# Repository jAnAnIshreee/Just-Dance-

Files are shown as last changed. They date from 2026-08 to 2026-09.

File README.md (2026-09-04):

# Just-Dance-
A from-scratch reimagining of the Wii game "Just Dance": custom motion controller hardware (TM4C ARM Cortex-M4, SPI IMU, DAC audio) running on-device ML for real-time dance recognition, with MQTT syncing multiple controllers over Wi-Fi. Group project.
 # TinyML Embedded Gesture Classifier

I built this project with a team of individuals as a real-time embedded gesture-recognition system with a custom PCB using TM4C123 microcontrollers, LSM6DSOX IMUs, ESP8266 wireless communication, and fixed-point TinyML inference.

<p align="center">
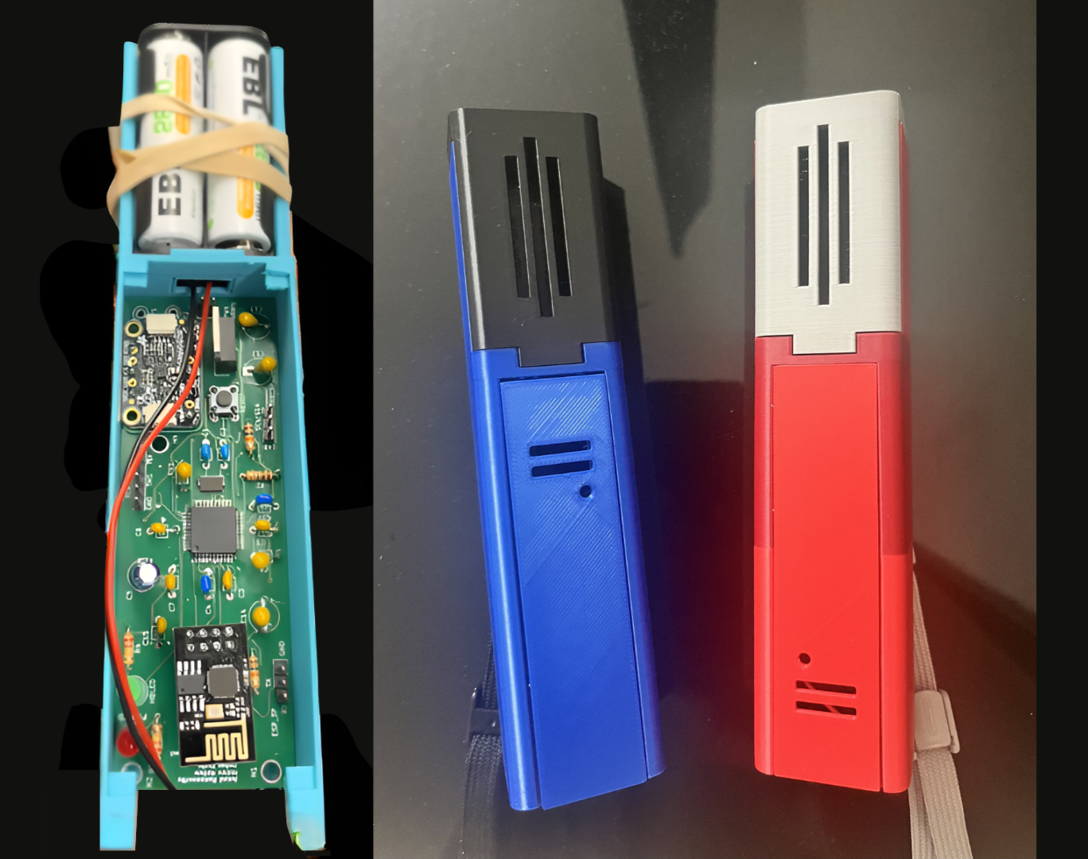
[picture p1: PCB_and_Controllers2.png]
  
</p>

<p align="center">
  <em>Custom PCB and handheld controller modules used in the embedded gesture classification system</em>
</p>

The system captures motion from handheld controller modules, segments raw IMU data into meaningful gesture windows, extracts engineered features, runs lightweight classifiers directly on-device, and streams results to a central hub and host display. The full pipeline runs on embedded hardware rather than relying on a PC for inference.

---

## Overview

My goal with this project was to design a complete embedded system capable of classifying human motion under tight hardware constraints.

Each controller:

* samples a 6-axis IMU in real time
* performs filtering and calibration
* segments motion into gesture windows
* extracts a compact feature vector
* classifies gestures using rule-based logic and TinyML models

A central hub coordinates timing, aggregates controller outputs over ESP8266, and forwards results to a PC over UART for visualization.

---

## Key Features

* Real-time gesture classification on TM4C123 microcontrollers
* LSM6DSOX accelerometer/gyroscope integration over I2C
* Deterministic scheduling using a free-running hardware timer
* Fixed 5-second calibration stage for bias stabilization
* Tunable motion segmentation engine
* 32-feature embedded feature extraction pipeline
* Fixed-point TinyML inference (no floating point at runtime)
* Hybrid detection: neural networks + rule-based scoring
* ESP8266 wireless communication between modules
* UART protocol for structured output (`SEG` and `DETECT`)
* EEPROM-backed configuration persistence
* Multi-module embedded architecture (controllers + hub + host)

---

## System Architecture

```text
Controller Modules (TM4C + IMU)
    ↓
Sensor processing + segmentation
    ↓
Feature extraction (32 features)
    ↓
TinyML / rule-based classification
    ↓
ESP8266 wireless messages
    ↓
Central Hub (TM4C)
    ↓
UART output
    ↓
Host PC (Python visualization/logging)
```

A key design decision I made was to keep all classification on the embedded controllers. The PC is only used for visualization and logging, not inference.

---

## Repository Structure

```text
sw/
  sw_Player1_Controller/   → Controller firmware
  sw_Player2_Controller/   → Second controller firmware
  sw_Audio/                → Central hub firmware
  sw_Display/              → Python host interface

hw/                        → KiCad hardware design files
Resources/                 → Datasheets and references
```

### Main Entry Points

* `sw_Player1_Controller/src/Lab1.c`
* `sw_Player2_Controller/sw/src/Lab1.c`
* `sw_Audio/sw/src_latest/Lab5.c`

---

## Embedded Gesture Pipeline

Each controller runs a full embedded ML pipeline:

```text
IMU read
→ axis remap
→ filtering
→ calibration
→ segmentation
→ feature extraction
→ classification
→ output
```

### IMU Processing

I read accelerometer and gyroscope data over I2C and remap axes into a consistent real-world coordinate system:

```text
IRL X = sensor Y  
IRL Y = sensor Z  
IRL Z = sensor X  
```

---

### Calibration

At startup, I run a strict 5000 ms calibration phase using timer-based scheduling. This avoids drift and ensures stable baseline values for bias and gravity compensation.

---

### Real-Time Scheduling

I use Timer0A as a free-running hardware timer and schedule all sampling relative to time instead of loop delays. This keeps behavior deterministic even with UART output or I2C latency.

---

### Motion Segmentation

I designed a segmentation engine that detects meaningful motion using:

* energy thresholds
* quiet-window detection
* min/max segment sizes
* cooldown timing

Each gesture can override segmentation parameters, which makes the system flexible across very different motion types.

---

## Feature Extraction

For each segment, I compute 32 engineered features describing motion shape and intensity.

Examples include:

* duration and sample count
* vertical displacement and total travel
* cross-body movement
* oscillation and slope changes
* total acceleration and gyro energy
* peak timing and normalized feature ratios
* spin characteristics
* energy per sample

Instead of feeding raw time-series data into a large model, I compress each gesture into a compact feature vector to stay within embedded constraints.

---

## TinyML Inference

I implemented small neural networks directly in firmware using fixed-point math.

Typical structure:

```text
16 inputs → 3 hidden (ReLU) → 1 output
```

All weights, biases, and normalization parameters are stored as scaled integers. This avoids floating-point overhead and keeps inference fast and deterministic.

Some gestures use ML models, while others use rule-based scoring depending on how well they can be defined analytically.

---

## Output Protocol

The system outputs structured UART messages:

### Feature Data

```text
SEG,<MOVE>,<32 values>
```

### Final Detection

```text
DETECT,<MOVE>,<score>
```

I use `SEG` for debugging/training and `DETECT` as the final classification output.

---

## Cumulative Scoring

Instead of classifying every segment independently, I accumulate scores across a gesture window and only output a final detection after enough evidence is collected.

This significantly reduces noise and false positives.

---

## Central Hub

The hub is another TM4C system that:

* synchronizes controller start timing
* receives wireless data from controllers
* forwards results over UART
* manages timing-sensitive coordination

---

## Host Interface

I wrote a Python interface using:

* `pyserial` for communication
* `tkinter` for UI
* `opencv` / `Pillow` for visualization

This layer is purely for monitoring—the embedded system performs all classification.

---

## Hardware

This system is built on:

* TM4C123 microcontrollers
* LSM6DSOX IMUs
* ESP8266 modules
* DAC/audio hardware (hub side)
* custom KiCad-designed boards

All hardware files are included in the `hw/` directory.

---

## Why This Project Matters

This project combines:

* real-time embedded systems
* IMU signal processing
* motion segmentation
* feature engineering
* TinyML on constrained hardware
* wireless embedded communication

The most important aspect is that the entire ML pipeline runs **on-device**, making it a true embedded TinyML system rather than a PC-based demo.

---

## Future Improvements

* Modularize controller firmware
* Formalize ML training/export pipeline
* Add evaluation metrics (accuracy, confusion matrix)
* Improve host visualization tools
* Add hardware/system diagrams

---

## Status

This is a working embedded system prototype with real-time gesture classification, multi-device coordination, and on-device ML inference. The core pipeline is fully implemented and functional on embedded hardware.

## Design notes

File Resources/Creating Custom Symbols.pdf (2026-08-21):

## Creating Custom Symbols

## Contents

Creating Custom Symbols | 1

Introduction

KiCad is a powerful open-source software suite for electronic design automation (EDA). It offers a comprehensive set of tools for schematic capture and PCB layout. While KiCad comes with an extensive library of symbols and footprints, there are times when you may need to create custom symbols and footprints to suit specific components or devices not available in the standard libraries or online.

Creating custom symbols allows you to represent components accurately in your schematics, while custom footprints enable precise placement and routing of PCB components.

Creating a Custom Symbol

A symbol in KiCad represents a component on your schematic. Every component on a schematic must be precisely represented to ensure the functionality and reliability of the final product. While KiCad offers a vast library of pre-made symbols, there are instances where designers encounter unique components or specialized devices not covered by the standard offerings.

To create a symbol, open the symbol editor.

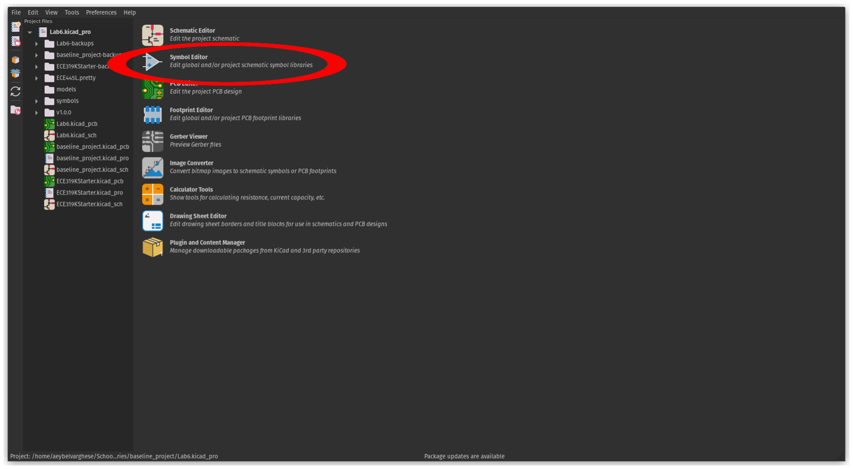
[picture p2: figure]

Figure 1: Main Menu

The KiCad Symbol Editor is a tool within the KiCad software suite specifically designed for creating and editing schematic symbols. It provides a user-friendly interface for designing graphical representations of electronic components, which are then used in schematics to illustrate circuit connections and layouts.

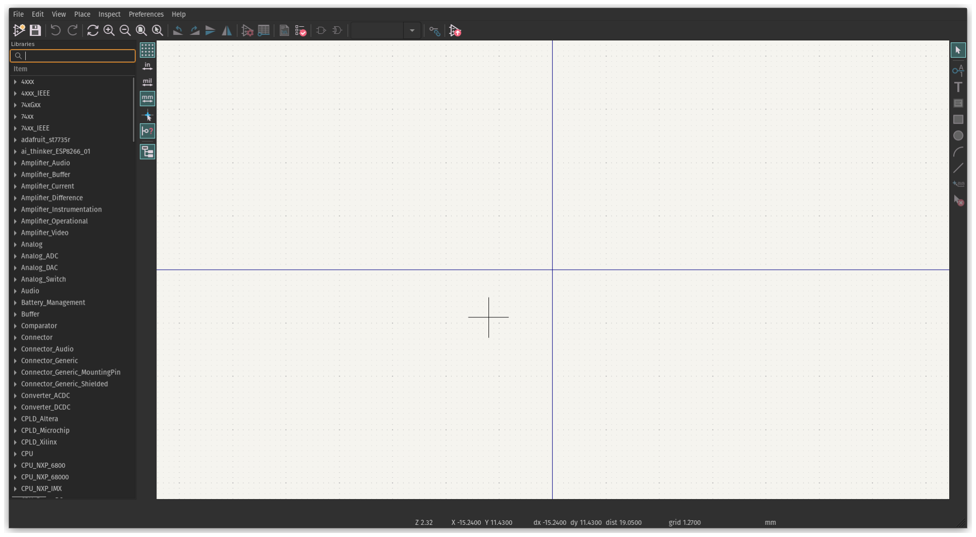
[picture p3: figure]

Figure 2: KiCad Symbol Editor

The Symbol Editor offers a graphical canvas where users can draw and manipulate schematic symbols using various drawing tools such as lines, arcs, polygons, and text boxes. The Symbol Editor allows users to save custom symbols to libraries for future use in other projects. Libraries can be organized and managed within KiCad to ensure easy access to custom symbols and efficient reuse across designs. Refer to the resource on adding libraries on more information regarding libraries.

When creating a symbol, it must be part of a library. We can either select a library to append a symbol to, or create a new library. To create a library, navigate to File → New Library, from here we can decide which symbol library table we want to add to, the global or project.

The global library table is shared amongst all your KiCad projects, while the project table is only for your currently open project. For this writeup, I am going to be adding it to the Project Table. When you press Ok, you can choose the location to save the “.kicad_sym” file which will contain your symbol library. You can choose any location you wish, although it is reccomended to have a folder dedicated for symbols organized in a reasonable matter. There is a “footprints” folder in the baseline project, and I will be storing the symbol library there. A entry in the symbol library table will be automatically made.

With a library selected in the left pane, press the “New Symbol Icon” or the Keyboard shortcut “N” to create a new symbol

Figure 3: Creating a symbol in the toolbar

Provide a name for the symbol, I am going to be creating a symbol for the MPU6050, (https://invensense.tdk.com/wp-content/uploads/2015/02/MPU-6000-Datasheet1.pdf) a IMU (Intertial Measurement Unit) from TDK InvenSense.

Creating symbols in KiCad involves designing graphical representations of electronic components to be used in schematics. Referring to datasheets during this process is crucial for accurately capturing the component’s electrical characteristics and pin configurations.

Referring to the pinout, we notice there are three categories of pins for this specific IC: power, communi-cation, and miscellaneous pins. We want to include all of these in our symbol. KiCad provides tools in the side toolbar to draw basic geometric shapes and describe pins.

Lets start by using the box tool to define the shape of our symbol.

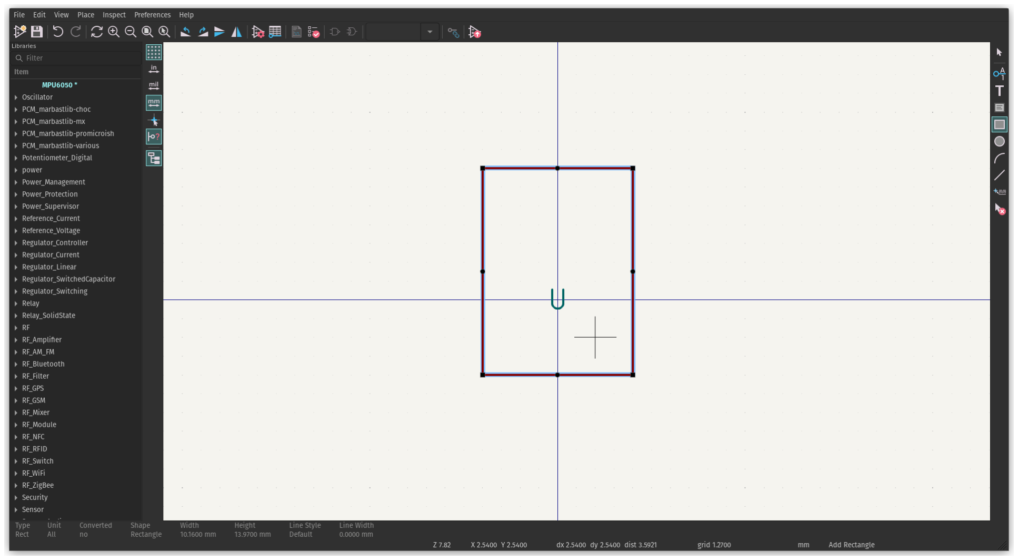
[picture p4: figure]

Figure 4: Box in Symbol Editor

With the shape of our pin assigned lets start adding pins. Select the “Add a Pin” button on the side toolbar, or press “P”.

When you press “Add a pin” in the KiCad Symbol Editor, you are prompted with several options to configure the properties of the pin being added to the symbol. These options allow you to define the electrical characteristics and behavior of the pin within the schematic symbol.

1. Name: This field allows you to specify the name of the pin, which is typically a descriptive label indicating the function or purpose of the pin within the component. Refer to the datasheet of the component for the name
2. Number: Here, you can assign a unique number to the pin. Pin numbers are used to identify individual pins within the symbol and are often based on the component’s datasheet or industry standards.
3. Orientation: This option determines the direction in which the pin is oriented within the symbol. You can choose from various orientations such as left, right, up, down.
4. Length: Specifies the length of the pin’s graphical representation within the symbol. This helps to visually distinguish pins of different lengths and aids in aligning pins with their corresponding connection points in the schematic.
5. Electrical Type: Defines the electrical characteristics of the pin, such as whether it is an input, output, bidirectional, power, or other special types. Selecting the appropriate electrical type ensures correct behavior during circuit simulation and layout as well as good for organization.
6. Visible: Determines whether the pin is visible or hidden in the symbol. Hidden pins are often used for internal connections or other purposes where the pin should not be displayed on the schematic.
7. Pin Function: This option allows you to specify additional information about the pin’s function or behavior, such as whether it is a clock input, reset signal, or other specialized function. This information aids in documentation and understanding the purpose of each pin within the symbol.

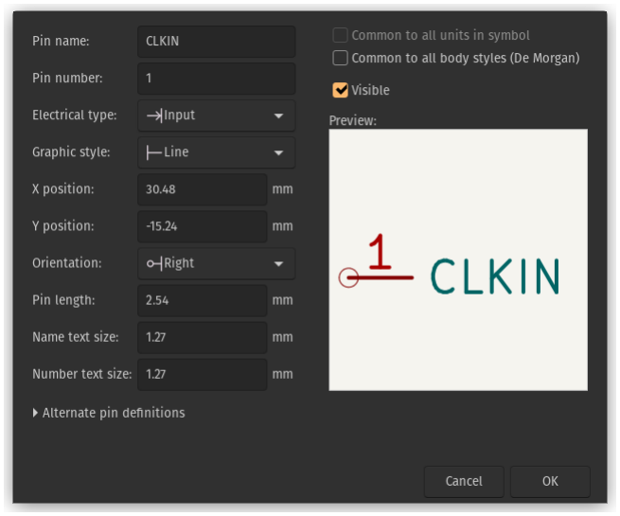
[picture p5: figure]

Figure 5: Describing a pin

Once we submit the options for the pin, we can place the pin down on our symbol.

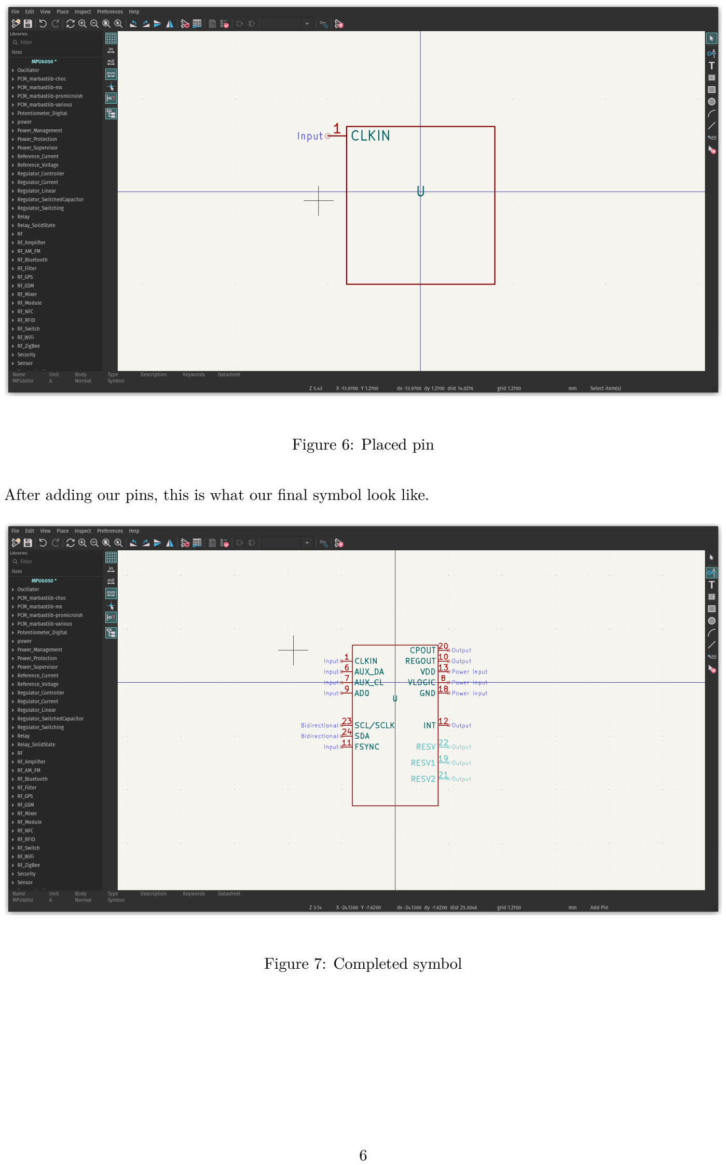
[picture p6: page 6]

Figure 6: Placed pin

After adding our pins, this is what our final symbol look like.

Figure 7: Completed symbol

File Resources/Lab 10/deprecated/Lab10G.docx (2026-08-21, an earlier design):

This laboratory assignment accompanies the book, Embedded Systems: Real-Time Interfacing to ARM Cortex M Microcontrollers, ISBN-13: 978-1463590154 (https://www.amazon.com/Embedded-Systems-Real-Time-Interfacing-Microcontrollers/dp/1463590156), by Jonathan W. Valvano, copyright © 2021.

## Goals

- To interface a DC motor using PWM so software can adjust delivered power
- To interface a tachometer so the software can measure speed
- To implement the data acquisition with input capture interrupts
- To implement the digital controller processing with periodic interrupts
- To study the behavior of the system as parameters to the proportional-integral (PI) controller are adjusted

## Responsibilities:

- Student 1: Motor and interface hardware and PWM output
- Student 2: Tach hardware and input capture measurement of speed
- Student 3: Digital Controller
- Student 4a: User interface (Blynk, UART, LCD)
- Student 4b: User interface UART0 to PC, command interpreter
- ALL: Tinker with variations of the PI control loop

Team Size: 4

Figure 10.1: Lab 10G Block Diagram.

## Review

- Valvano Section 6.1.3 about using input capture to measure period
- Valvano Section 6.3 about generating PWM outputs
- Valvano Section 6.5 about interfacing a DC motor with a IRLD024 or IRLD120
- IRLD120 data sheet (https://www.dropbox.com/s/ulcq0selng2aqfx/IRLD120.pdf?dl=1)
- IRLD024 data sheet (https://www.dropbox.com/s/u49pvrn8jz70aru/sihld24.pdf?dl=1)
- Pololu motor https://www.pololu.com/product/3675
- Valvano Section 6.6 about integral control (you will need to add proportional control (https://www.et.byu.edu/~tom/classes/436/ClassNotes/Class07-PI.pdf))

## Starter files

- PWM_4C123 PeriodMeasure_4C123
- PeriodicTimer0AInts_4C123
- Python starter 4/13/22 https://www.dropbox.com/s/xow3r4eumwcakj0/Python.zip?dl=1
- Lab 10G Eagle starter Schematic
- (https://www.dropbox.com/s/pyssg7koidkfg54/Lab10_Starter.sch?dl=1)EE445M http://users.ece.utexas.edu/%7Evalvano/arm/MotorTestProject.zip
- EE445M https://www.dropbox.com/s/vtjc5j6hz9b15dj/SensorTestProject.zip?dl=1

## Required Hardware (hardware groups building with discrete parts)

EK-TM4C123GXL https://store.ti.com/ (https://store.ti.com/ProductAccessories.aspx?ProductId=4505) $12.99

Sitronix ST7735 Color LCD http://www.adafruit.com/products/358 $19.99

Pololu item #3675 https://www.pololu.com/product/3675 $13.95

1N914B 4ns switching diode

Two 10k resistors

IRLD024 or IRLD120 MOSFET

## Background

The advantages of DC motors include low cost, high speed, and high torque. However, they need sensors and closed-loop controllers in order to operate them with predictable responses. Applications of DC motors include electric cars, robotics, industrial machines (pumps, drills, mills, and lathes), consumer products (blender, washing machine, and AC/heaters) and medical devices (pumps). In this lab, you will spin a brushed DC motor (Figure 10.2) at a constant speed using a proportional-integral (PI) controller. The user interface will allow the operator to increase or decrease the desired speed. A tachometer will be used to measure the motor speed. A background periodic interrupt will execute the three steps of a digital controller.

1. Calculate error as the difference between actual and desired speed
2. Execute a control equation to determine the next output
3. Adjust the power to the actuator in an attempt to drive the error to zero

The software will set the power delivered to the motor using pulse-width-modulation (PWM). The essence of an integral controller is the amount you add to the power is linearly related to the error. If the motor is spinning much too slowly, you will increase power a lot. If the motor is spinning just a little bit too slowly, you will increase power a little bit. If the motor is spinning much too quickly, you will decrease power a lot. If the motor is spinning just a little bit too quickly, you will decrease power a little bit. The input capture input and the PWM output must be written at a low level, like the book, without calling TivaWare driver code. No TivaWare code is allowed.

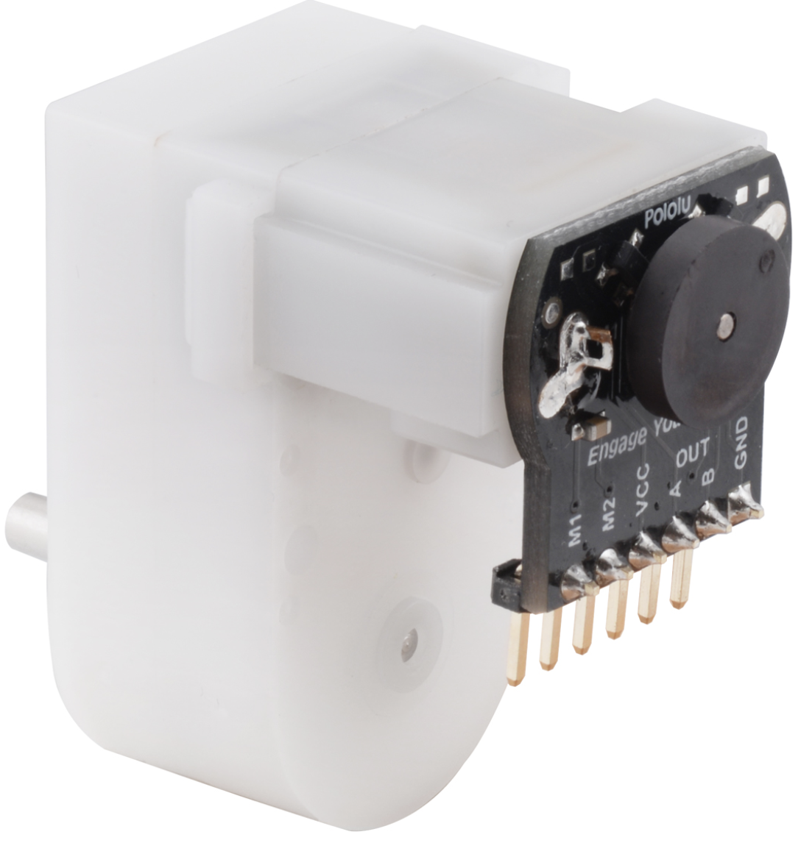
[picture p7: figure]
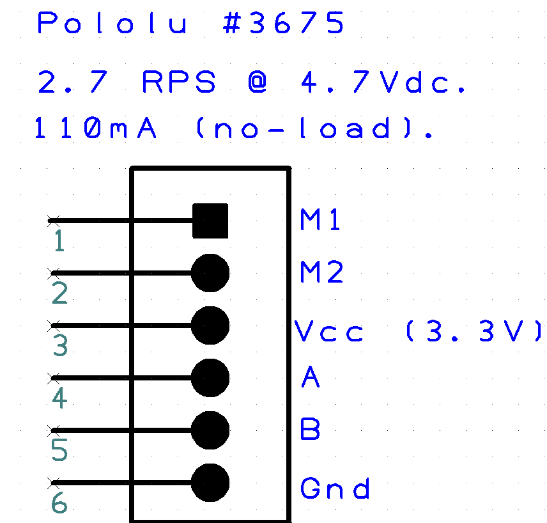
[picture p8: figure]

Figure 10.2. Hardware groups use Pololu item #3675. M1 and M2 connect to the DC motor and the other four wires are the tachometer. Do not ground A or B, they are outputs.

Figure 10.3 shows a possible data flow graph.

Figure 10.3. Option 1) Lab 10G data flow graph.

Student 4 creates a mechanism to visualize and control the system

Option 1) Student 4 implements Blynk

Option 2) Student 4 implements UART0/USB/PC/Python

Figure 10.4 shows a possible call graph.

Figure 10.4. Lab 10G call graph.

Option 2) replace Blynk with UART0/USB/PC/Python

## Student 1 Motor Interface

Choose Port-B[6] on the TM4C123 for the PWM output. The LM4F120 does not have hardware PWM. So, if you have an LM4F120 LaunchPad you will need to use one of the timers to create the PWM output. Use a 10k resistor into the gate to reduce transients. Use a 1N914 (any fast diode is ok) to remove back EMF caused by the V=L*dI/dt across the motor (see Figure 10.5). Connect M2 to +5V and use the IRLD024/IRLD120 to sink current from the M1 to ground. Refer to IRLD024/IRD120 interface in aLec42_DC_Motors.pptx (https://www.dropbox.com/s/ez9kxdaawj3j3xy/aLec42_DC_Motors.pptx?dl=1).

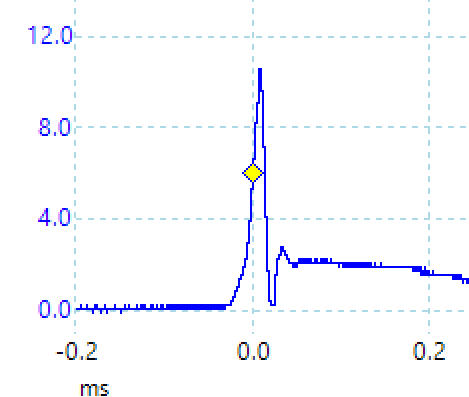
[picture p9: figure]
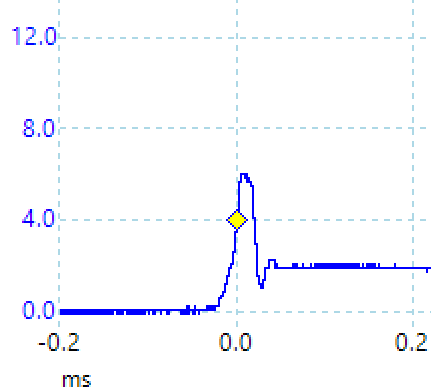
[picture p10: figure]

Figure 10.5. Voltage from drain to source (motor – to ground) when current is removed. The left response was measured without the 1N914 shunt diode and the response on the right was measured with the 1N914 shunt diode. The steady state 2-3V output after 0.05ms occurred because the pin was floating at the point in time

In order to choose a PWM period you will need to know the time constant of your motor. Figure 10.6 is measured speed as a function of time as PWM is increased from 25 to 50%. You can estimated the time constant of this motor to be 50 ms. Therefore if the PWM period is 1ms, the motor will only respond to the average power (duty cycle), and not to the individual high and low signals of the interface.

Figure 10.6. Step response of the DC motor used to estimate the time constant. Expect your measured speeds to be slower (this data was collected at 7.2V.)

## Student 2 Tachometer Interface

To interface the tachometer, connect VCC to 3.3V and GND to GND. Choose a TM4C123 pin that supports input capture interrupts. Use a 10k pullup to 3.3V for the tachometer output (A or B). You can use either A or B. You could interface both A and B to input capture if you wished to reduce the time to measure speed or if you wished to measure direction. There are 12 tachometer pulses per rotation (https://www.pololu.com/product/3542). Figure 10.7 shows the tachometer output of 973.4 Hz, ~~which is~~ ~~60*~~~~973.4/360 rp~~~~m~~ ~~=~~ ~~162~~ ~~rp~~~~m~~. If the motor spins from 0 to 162 RPM, then choose a fixed-point resolution of 0.1 or 0.01 RPM. Choose a resolution based on the ability of the tachometer to measure speed at 100 RPM.

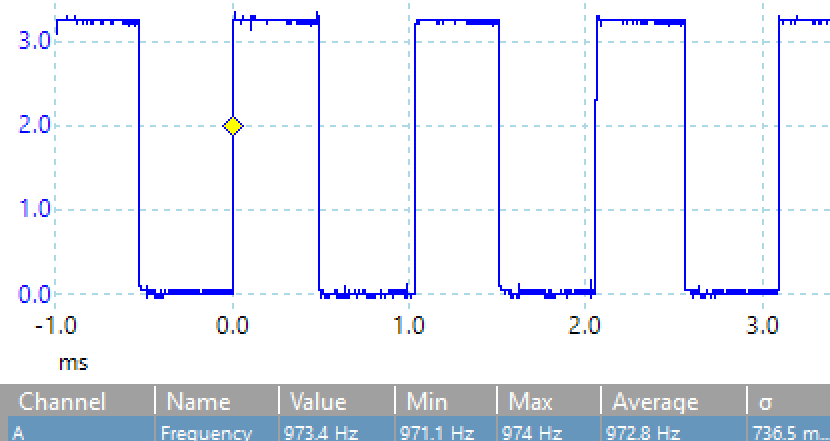
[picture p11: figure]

Figure 10.7. Tachometer output at full speed.

The tachometer interface may require filtering to improve SNR. However, be careful to minimize time delay. Time delays in the digital controller will cause the system to be unstable. For any digital filter measure the step response. A simple measure of filter delay is to make input go from …x,x,x,x,y,y,y,y… and determine many samples it takes for the output of the filter to reach x+(y-x)e⁻¹. For example, the delay of a 3-wide median filter is 1 sample.

You will need a separate periodic timer interrupt to determine if the motor is spinning too slow to be accurate or not spinning at all.

## Student 3 Digital Controller Design

A closed loop feedback is required because not all motors are created equal. In Figure 10.8 we see the results from 8 different motors (the ones from the lab board, not this one however). One of the first steps in designing a digital controller is to make an estimate of motor speed in RPM versus PWM duty cycle. This curve will help estimate the range of speeds that your controller will be able to manage. In other words, what speeds correspond to duty cycles from 25 to 75%? Note: this response is highly dependent on friction. We expect the usable range to be around 50 to 120 RPM, but your motor may be different. You are free to control speed in rps or RPM as long as the fixed point resolution matches the tachometer error. The design progression is

1. Incremental (stable but slow)
2. Integral (stable, a little faster)
3. Proportional-integral (may be unstable, fast)

## Student 4 Blynk Control Interface or UART/Python Interface

Convert the Lab 4D Blynk code to provide variables to the PI control loop and display the key output values of the motor controller on the LCD. See figures 10.8, 10.12-10.15 below.

## Requirements Document

1. Overview

1.1. Objectives: Why are we doing this project? What is the purpose?

The objectives of this project are to design, build and test a brushed DC motor controller. The motor should spin at a constant speed and the operator can specify the desired set point. Educationally, students are learning how to interface a DC motor, how to measure speed using input capture, and how to implement a digital controller running in the background.

1.2. Process: How will the project be developed?

The project will be developed using the TM4C LaunchPad. The user will use switches or the UART to specify the desired speed of the motor as well as the “K” terms for the Proportional and Integral components of the PI controller. The system will be built on a solderless breadboard and run on the usual USB power. A hardware/software interface will be designed that allows software to control the DC motor. There will be at four hardware/software modules: motor controller output, tachometer input, digital controller, and user interface with switches, UART and LCD. The process will be to design and test each module independently from the other modules. After each module is tested, the system will be built and tested.

1.3. Roles and Responsibilities: Who will do what? Who are the clients?

EE445L students are the engineers and the TA is the client. Student 1 will design build and test the motor controller output. Student 2 will design build and test the tachometer input. Student 3 will design build and test the digital controller. Student 4 will design build and test the user interface with switches. All students will work performance measurements and tuning the controller. (note to students: you are expected to make minor modifications to this document in order to clarify exactly what you plan to build. Students are allowed to divide responsibilities of the project however they wish, but, at the time of demonstration, both students are expected to understand all aspects of the design.)

1.4. Interactions with Existing Systems: How will it fit in?

The system will use the microcontroller board, a solderless breadboard, and the DC motor shown above in Figure 10.2. The wiring connector for the DC motor is described in aLec42_DC_Motors.pptx (https://www.dropbox.com/s/ez9kxdaawj3j3xy/aLec42_DC_Motors.pptx?dl=1).

1.5. Terminology: Define terms used in the document.

For the terms Proportional-Integral (PI) controller, PWM, board support package, back EMF, torque, time constant, and hysteresis, see textbook for definitions.

1.6. Security: How will intellectual property be managed?

The system may include software from TivaWare and from the book. No software written for this project may be transmitted, viewed, or communicated with any other EE445L student past, present, or future (other than the lab partner of course). It is the responsibility of each team to keep its EE445L lab solutions secure.

2. Function Description

2.1. Functionality: What will the system do precisely?

The palette for the Blynk App (Fig 10.8) will have the following 8 virtual pin components:

- Slider to control the desired motor speed
- Two sliders to control the “K” multiplier/divider for the Proportional term
- Two sliders to control the “K” multiplier/divider for the Integral term
- RPS Value display
- PWM Duty Cycle Control Value (U)
- PI Error Value (E)
- Optional: Proportional and Integral Term values

Remember to delete the Widgets from Lab 4 so that you don’t have to buy new tokens for this Lab.

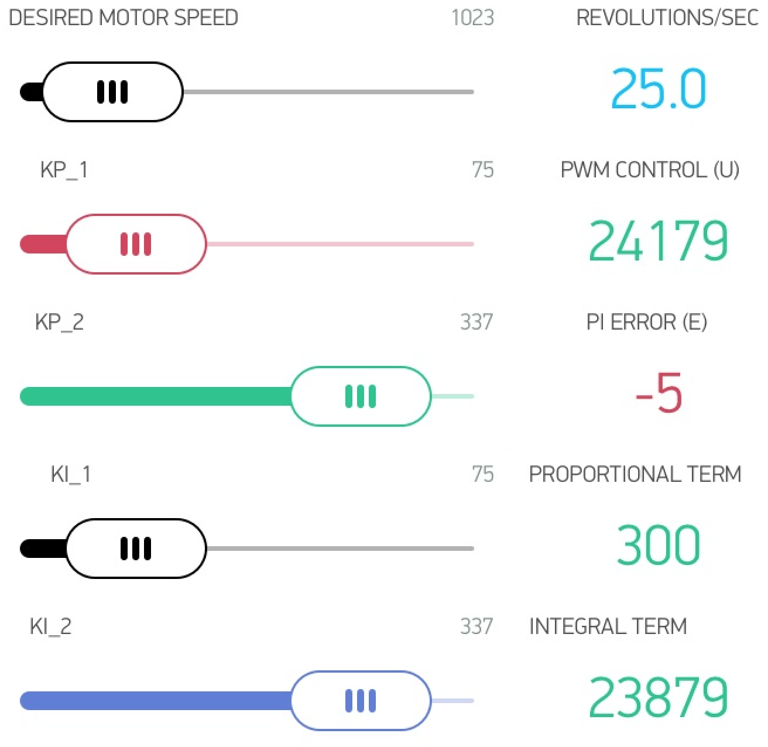
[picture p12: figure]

Figure 10.8 Blynk App palette (feel free to remove the Motor RPS so you’ll not have to buy tokens) Feel free to make this user interface however you wish. You may also have to delete the Lab 4 Blynk app

The PI control equation should be in this form:

MotorSpeed = rps/40; // Set the Motor Speed

P = (Kp1 * E)/Kp2; // Proportional term

if(P < 300) P = 300; // Minimum PWM output = 300

if(P >39900) P = 39900; // Maximum PWM output = 39900

I = I + (Ki1 * E)/Ki2; // SUM(KiDt)

if(I < 300) I = 300; // Minimum PWM output = 300

if(I >39900) I = 39900; // Maximum PWM output = 39900

U = P + I; // Calculate the actuator value

if(U < 300) U=300; // Minimum PWM output

if(U >39900) U=39900; // 3000 to 39900

PWM0A_Duty(U); // Send to PWM

The motor speed should start out at zero RPS. Once the desired motor speed slider is adjusted the motor should start. (Note to students: feel free to change how the set point is established, and feel free to increase or decrease the maximum speed in accordance to how it actually works.)

Both the desired and actual speeds should be plotted on the color LCD as a function of time similar to Figure 10.11 The actual speed should also be graphically shown on the Blynk App. (note to students: feel free to specify exactly how the data is displayed. For example, you could but do not have to add numerical outputs).

2.2. Scope: List the phases and what will be delivered in each phase.

Phase 1 is the preparation; phase 2 is the demonstration; and phase 3 is the lab report. Details can be found in the lab manual.

2.3. Prototypes: How will intermediate progress be demonstrated?

A prototype system running on the LaunchPad and solderless breadboard will be demonstrated. Progress will be judged by the preparation, demonstration and lab report.

2.4. Performance: Define the measures and describe how they will be determined.

The system will be judged by three qualitative measures. First, the software modules must be easy to understand and well-organized. Second, the system must employ a PI controller running in the background. There should be a clear and obvious abstraction, separating the state estimator, user interface, the controller and the actuator output. Backward jumps in the ISR are not allowed. Third, all software will be judged according to style guidelines. Software must follow the style described in Section 3.3 of the book (note to students: you may edit this sentence to define a different style format). There are three quantitative measures. First, the average speed error at a desired speed of 60 RPM will be measured. The average error should be less than 5 RPM. Second, the step response is the time it takes for the new speed to hit 100 RPM after the set point is changed from 50 to 100 RPM. Third, you will measure power supply current to run the system. There is no particular need to minimize controller error, step response, or system current in this system.

2.5. Usability: Describe the interfaces. Be quantitative if possible. Describe the how the Blynk App will control the motor.

2.6. Safety: Explain any safety requirements and how they will be measured.

We expect the motor current to be less than 120 mA. Please place a current probe on the motor interface the first couple of time you run the motor to make sure you have wired it correctly. However, under heavy friction this current could be 2 times higher. Therefore, please run the motor unloaded. Connecting or disconnecting wires on the protoboard while power is applied will damage the microcontroller. Operating the circuit without a snubber diode will also damage the microcontroller.

3. Deliverables

3.1. Reports: How will the system be described?

A lab report described below is due by the due date listed in the syllabus. This report includes the final requirements document.

3.2. Audits: How will the clients evaluate progress?

The preparation is due at the beginning of the lab period on the date listed in the syllabus.

3.3. Outcomes: What are the deliverables? How do we know when it is done?

There are three deliverables: preparation, demonstration, and report. (Note to students: you should remove all notes to students in your final requirements document).

## Preparation (do this before your lab period)

1. Copy and paste the requirements document from this document. Edit it to reflect your design.
2. Edit the Lab_10G.sch (https://www.dropbox.com/sh/2lzrbx88r8cgw05/AADl2iDcrez1SNAoDAh33-Kya?dl=1) file showing the interface to the motor and to the tachometer. Make sure your TA approves the design before connecting it to the microcontroller. Include pin numbers and resistor/capacitor types and tolerances. Power the motor from the USB +5V and not +3.3V. This interface will require a 1N914 snubber diode. If do not properly connect this diode, the back EMF will destroy your microcontroller and possibly your laptop if it is connected to the TM4C board.

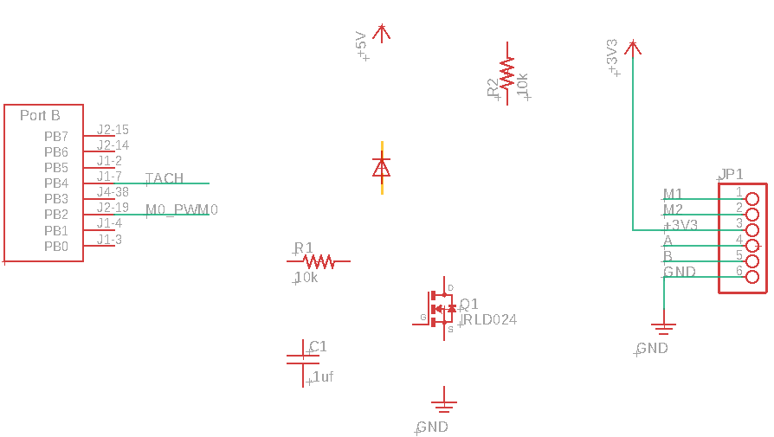
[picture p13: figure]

3. Design four software modules that implement the digital controller. A “syntax-error-free” version of the header files is required as preparation. This will be checked off by the TA at the beginning of the lab period. If you wish to see more timer and PWM examples, see the EE445M sensor board and motor board starter projects (see starter files above).

## Student 1 Procedure (do this during your lab period)

With an ohmmeter, measure the resistance of the motor coil. The very fast turn-off times of the digital transistors can easily produce large back EMF voltages, so please test the hardware before connecting it to the microcontroller. Make sure your TA checks your hardware diagram before connecting it to the microcontroller.

Build the hardware interface to the motor. However, before connecting it to the microcontroller, you must use a simple switch to simulate a PWM output of 100%. Connect a current meter in series with the motor current path. Measure the motor current at full speed (100% duty cycle). Please contact your professor or TA if this current is vastly different from 120mA. Measure also the voltage drop across the motor at full speed (100% duty cycle). Call this full speed motor voltage Vm. The voltage drop across the MOSFET VDS should be much less than 1V. Note: VDS + Vm should equal 5V.

Test the PWM output with a scope or logic analyzer before connecting it to the motor. Write software so a switch causes the PWM to cycle through 10%, 30%, 50%, 70% and 90%.

Remove the switch, connect the PWM to the motor circuit, and reconnect the current meter in series with the motor current path. Using the PWM output in open loop fashion measure the motor current at duty cycles 10%, 30%, 50%, 70% and 90%. Do this under no load. Estimate the average motor voltage as duty*Vm. Create a graph similar to Figure 10.9 below. Plot the straight line suggested by the ohmmeter measurement of motor resistance.

Figure 10.9 was measured with the Lab board motor, so expect your measurements to be different. However, the motor does not behave like a simple resistor.

Figure 10.9: The current to the Lab board DC motor is plotted versus applied voltage. Notice the DC motor does not behave like a resistor. This response will also be a function of the mechanical torque (or friction) applied to the shaft.

## Student 2 Procedure (do this during your lab period)

Build the hardware interface to the tachometer. Using a scope (real or TExaSdisplay), verify the tachometer interface generates a digital (0V and 3.3V) signal like Figure 10.7. Speed measurement must occur in the background using an input capture and periodic interrupt.

Using the PWM output in open loop fashion measure the motor speed at duty cycles 10%, 30%, 50%, 70% and 90%. Do this under no load. Estimate the average motor power as duty*Im*Vm. Create a graph similar to Figure 10.10 below.

Figure 10.10: The motor speed is plotted versus applied power on seven different motors. Power is motor voltage multiplied by motor current multiplied by PWM duty cycle. Motor speed (RPS) is tachometer frequency (Hz) divided by 4. Notice at 100 mW, these DC motors do not spin at all. Also notice the variability between these seven motors. This response will also be a function of the mechanical torque (or friction) applied to the shaft.

## Student 3 Procedure (do this during your lab period)

After you are sure the motor and tachometer interfaces are operating properly, test a simple incremental controller, see Figure 10.11. Choose a PWM period, a range of usable speeds, and a controller rate consistent with the data collected in the above two procedures.

Figure 10.11: Incremental controller. Change the +3, -3, +100, -100, 14898 constants.

Debug the integral motor controller. Consider calculating speed as a decimal fixed-point number in 0.1 or 0.01 RPM. The periodic interrupt-driven background thread will execute the digital controller, while the foreground thread initializes the system then performs human interface. An integral controller is pretty stable. If the speed oscillates wildly (all stop- full speed) then decrease the controller constant. If it is VERY slow to respond, increase the constant.

## Student 4 Procedure (do this during your lab period)

Student 4 creates a mechanism to visualize and control the system

Option 1) Student 4 implements Blynk

Option 2) Student 4 implements UART0/USB/PC/Python

Option 1) Setup the user interface that runs in the main program. See requirements document for details. Your system performance display on the LCD should be similar to Figure 10.12 through 10.15 and the YouTube video, http://youtu.be/ug-ZlOSbb4M.

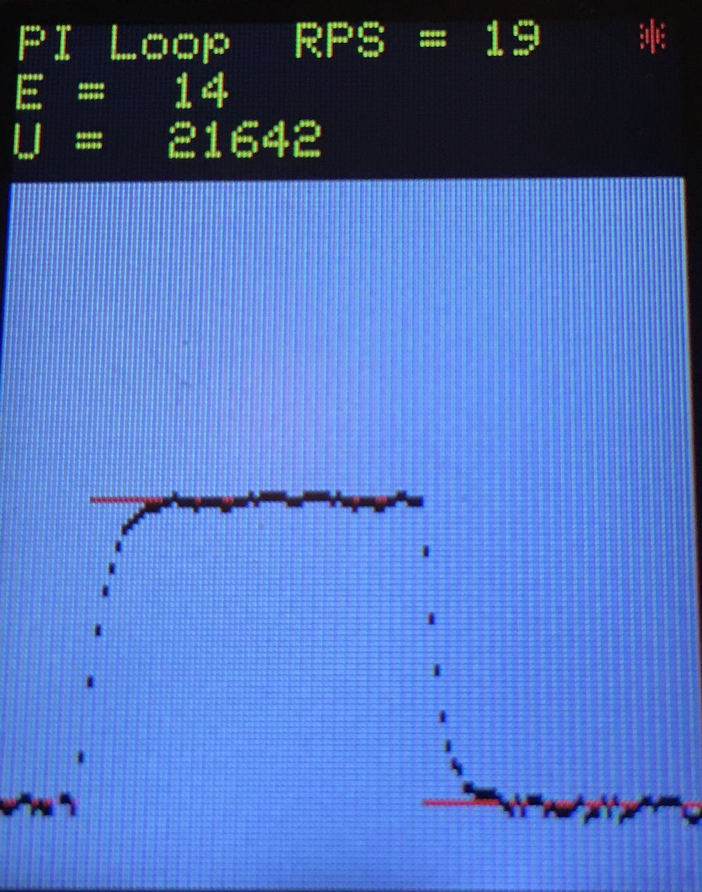
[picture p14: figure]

Figure 10.12: Measured and desired speeds are plotted versus time as the set point is increased from 20 to 50 RPS. NOTE: This is an optimally damped PI Loop (Lab board motor)

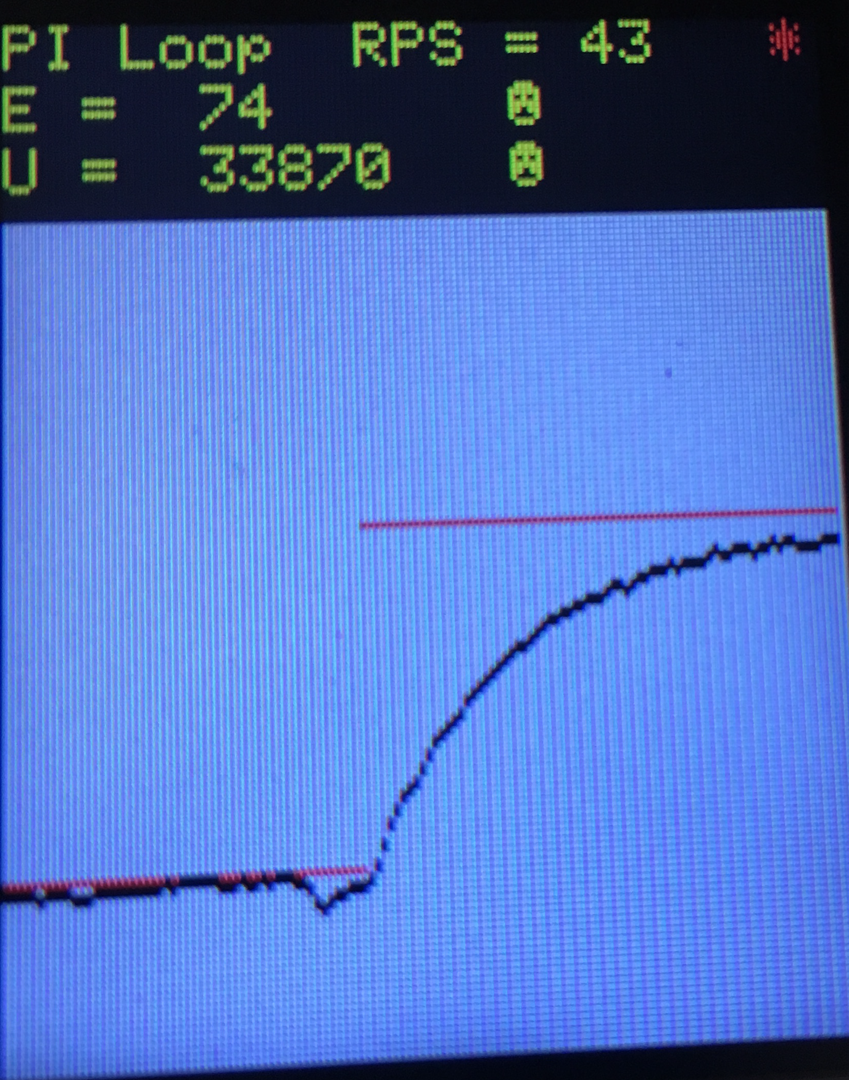
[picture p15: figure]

Figure 10.13: Over-damped PI Loop

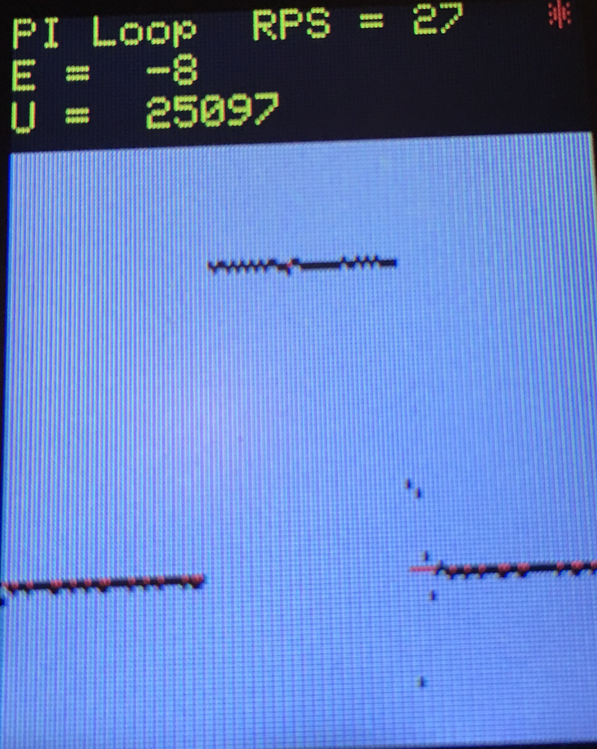
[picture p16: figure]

Figure 10.14: Under-damped PI Loop

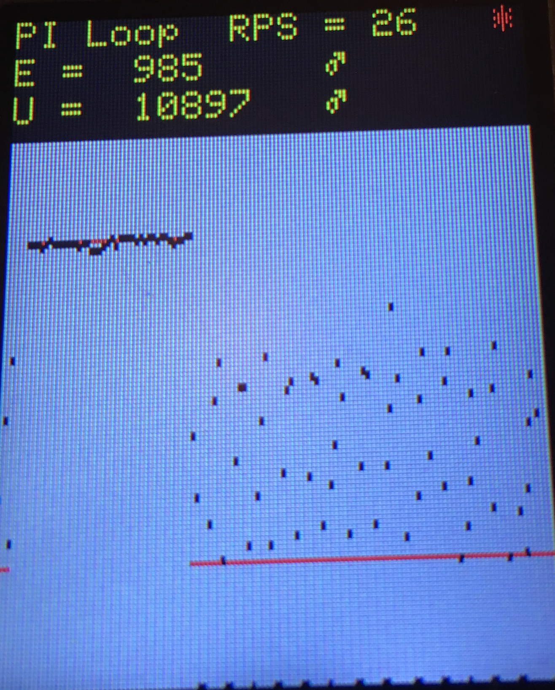
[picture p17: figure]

Figure 10.15: Unstable PI Loop

The Blynk or Python user interface should facilitate changing controllers and controller parameters. You should be able to demonstrate without recompiling.

## Student-all Procedure (do this during your lab period)

Measure the maximum time to execute each of your ISRs.

For each of the three controllers, what is the average controller error (difference between desired and actual speed)? The PI controller is optional.

For each of the three controllers, what is the approximate time it takes the speed to stabilize after the set point is increased from 40 to 90 RPM? Feel free to change these two set points has appropriate for your system. You do not need to tweak the system to minimize error or response time.

## Deliverables (exact components of the lab report)

1. Objectives (final requirements document)
4. Hardware Design (PCB Artist file)

DC motor and tachometer interfaces, showing all external components

LCD and switch interfaces, showing all external components

Include both these in a schematic

5. Software Design (upload your files as instructed by your TA)

Make sure to include units on all your software variables

Make a clear distinction between variables used for debugging and variables needed in the controller

Data flow and call graph: copy Figures 10.3 and 10.4, and edit as necessary

6. Measurement Data (underlined sections of the lab manual)

Procedure 1) Give the voltage, current, and resistance measurements. Plot motor current vs duty*Vm.

Procedure 2) Typical plot of the tachometer like Figure 10.7. Motor speed vs PWM. Plot of motor speed vs power, like Figure 10.8.

Procedure 4) We define locking as the condition when the error eventually goes to approximately zero. Four screen shots of the hardware in operation -> switching from minimum speed to

maximum speed or vice versa:

a) Normal operation – optimal response time (locking). Fig 10.11

b) Slow loop response time (locking) Fig 10.12

c) Fast loop response time (locking) Fig 10.13

d) Unstable (unable to lock) Fig. 10.14

Procedure-all) Specify the maximum time to execute once instance of the ISR. Determine the percentage time required to run all ISRs.

Procedure-all) Specify the average controller error for three controllers

Procedure-all) Specify the approximate response time for three controllers

7. Analysis and Discussion (give short 1 or two sentence answers to these questions)
a. What is torque? What are its units?
b. Draw an electrical circuit model for the DC motor coil and explain the components. Use this circuit model to explain why the current goes up when friction is applied to the shaft
c. Explain what parameters were important for choosing a motor drive interface chip (e.g., IRLD024/IRD120). How does your circuit satisfy these parameters?
d. You implemented an integral controller because it is simple and stable. What other controllers could you have used? For one other type of controller how would it have been superior to your integral controller.
e. It the motor is spinning at a constant rate, give a definition of electrical power in terms of parameters of this lab? Research the term “mechanical power”. Give a definition of mechanical power. Are the electrical power and mechanical power related?

## Checkout (show this to the TA)

You should be able to demonstrate correct operation of the DC motor system. Be prepared to describe how your motor interface works. Demonstrate debugging features that allow you to visualize the software behavior. Show the TA the four modes specified in the Deliverables Section-4: Normal operation, Slow loop response time, Fast loop response time and Unstable mode.

All software and report files must be uploaded as instructed by your TA.

## Hints

1. You should use a periodic interrupt to determine if the motor is stopped or spinning very slowly.
8. The USB +5V regulated supply is specified to 500 mA total current. We strongly suggest you do not mechanically load the motor. It runs 120 mA unloaded, but much larger if you load the motor. If your PC disconnects you, then you will need to power cycle your computer and restart the OS.

Jonathan W. Valvano & Mark McDermott

Lab 10G DC Motor Control Fall 2022 Page 10.

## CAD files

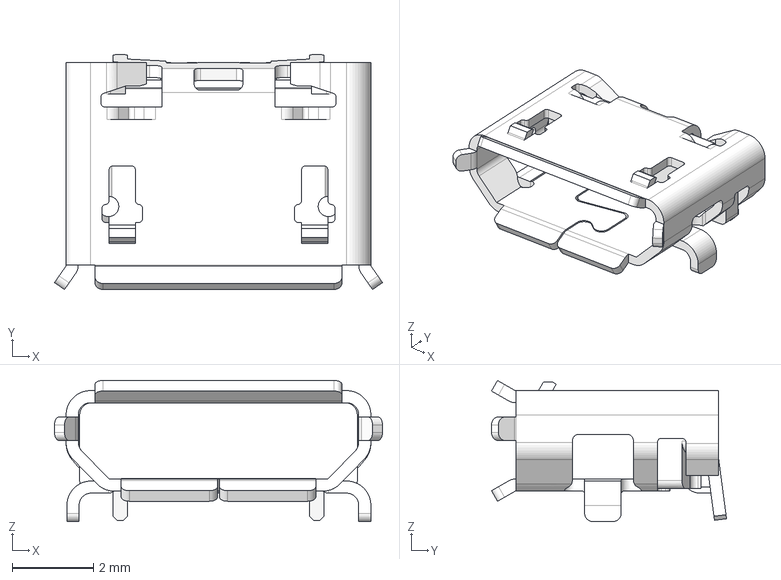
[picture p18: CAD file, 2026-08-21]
hw/Part Libraries/models/ZX62D-B-5PA8.stp
8.09 x 5.80 x 3.48 mm

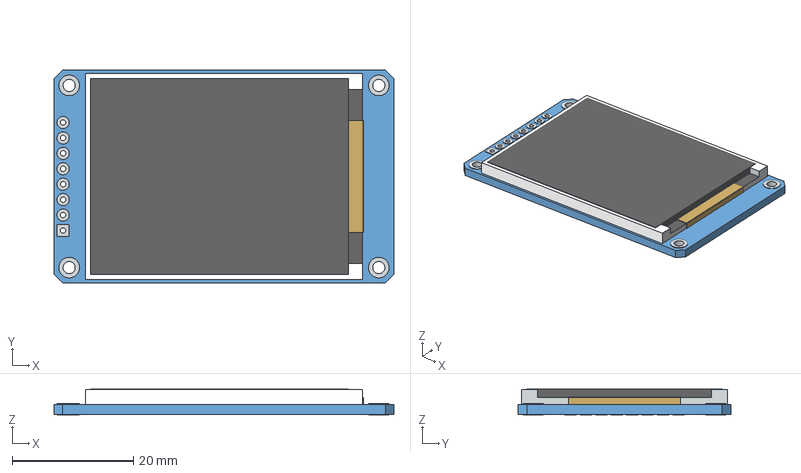
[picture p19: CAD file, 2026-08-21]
hw/Part Libraries/models/adafruit_st7735r.stp
56.0 x 35.0 x 4.25 mm

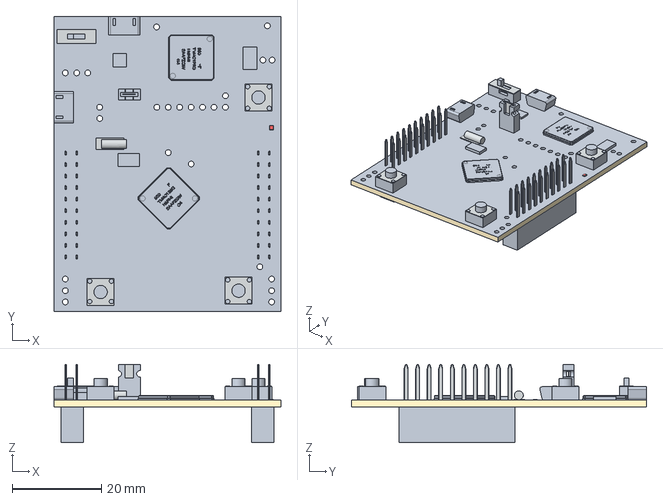
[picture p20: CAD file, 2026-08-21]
hw/Part Libraries/models/ti_EKTM4C123GXL.step
50.8 x 66.0 x 17.5 mm

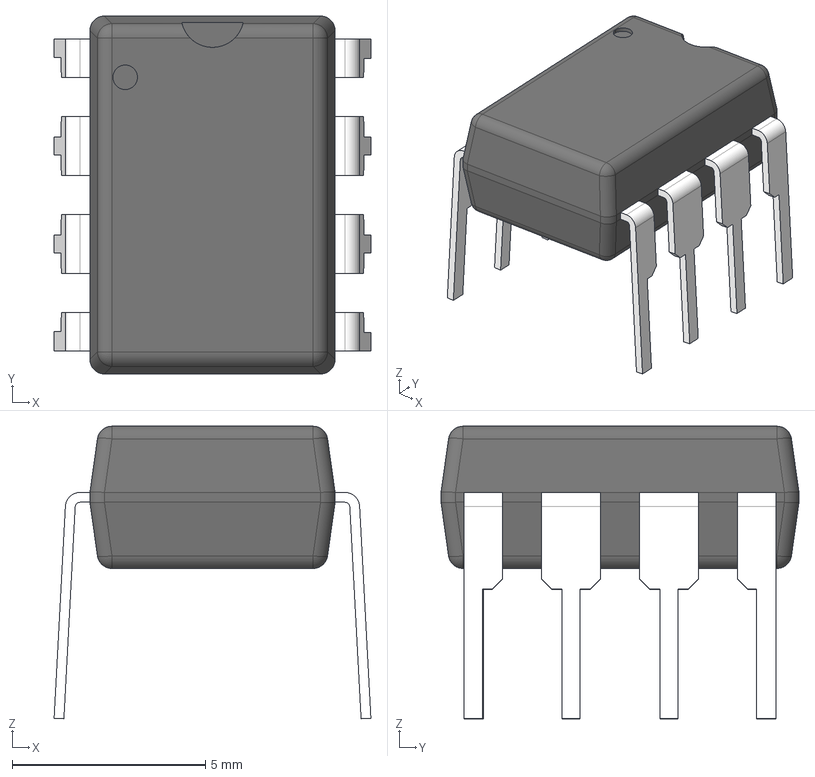
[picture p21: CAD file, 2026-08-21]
hw/Part Libraries/models/ti_TLV5618AIP.stp
8.20 x 9.27 x 7.58 mm
BODY_P0008A
LEAD_P0008A x 4
LD_LHALF_P0008A x 2
LD_RHALF_P0008A x 2

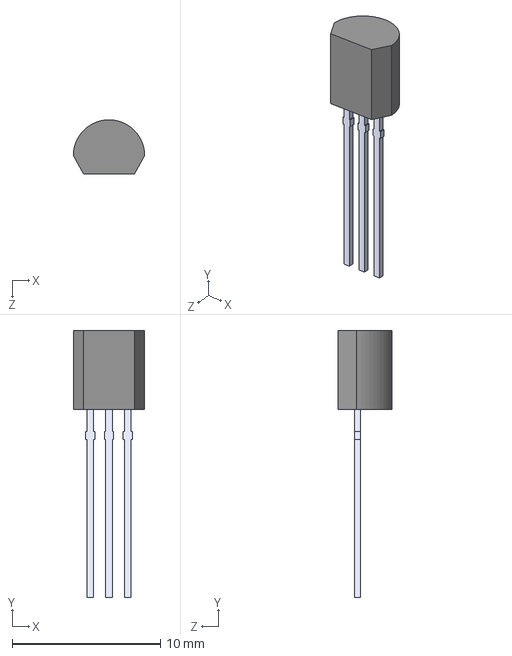
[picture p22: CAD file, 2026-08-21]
hw/Part Libraries/models/ti_LM4041CILPR.step
4.82 x 18.0 x 3.68 mm

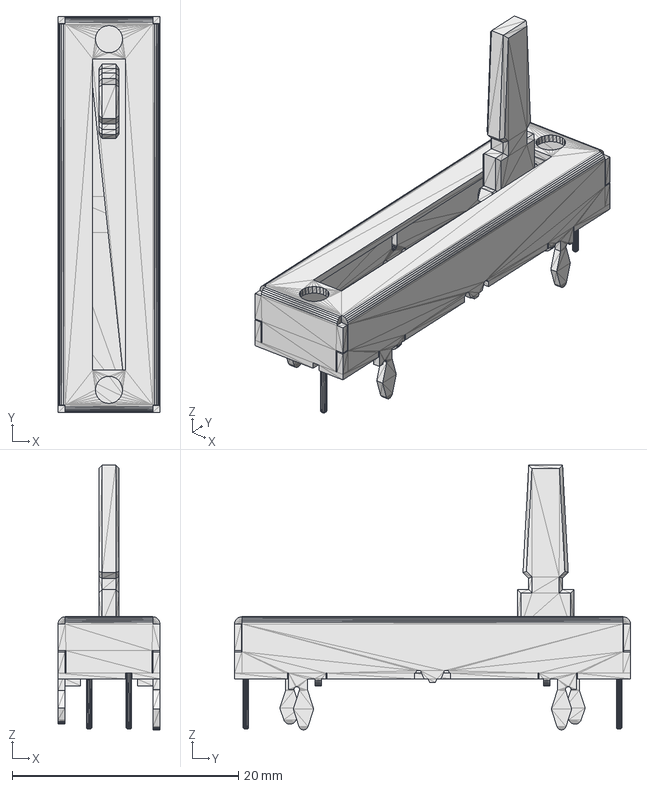
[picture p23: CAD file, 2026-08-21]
hw/Part Libraries/models/PTA2043.stp
9.00 x 35.0 x 23.4 mm

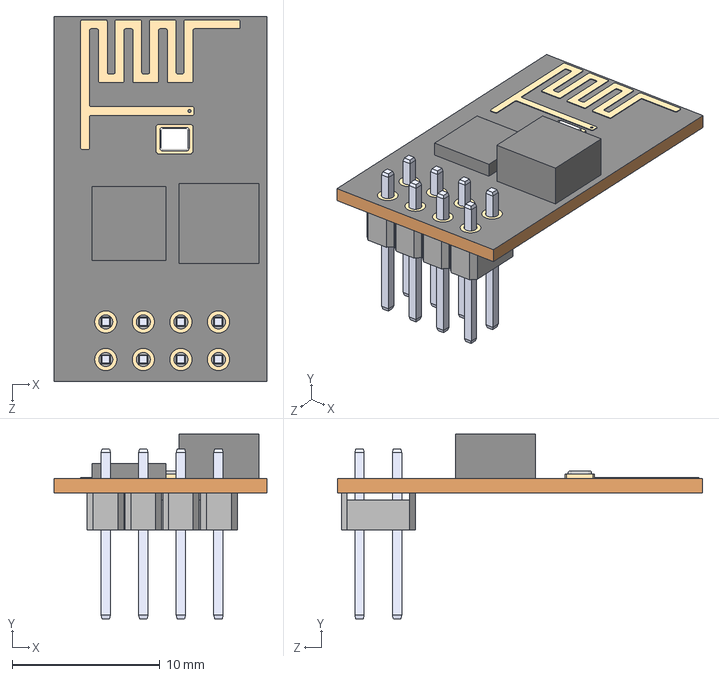
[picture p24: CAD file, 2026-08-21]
hw/Part Libraries/models/ai_thinker_ESP8266-01.step
14.4 x 12.5 x 24.7 mm

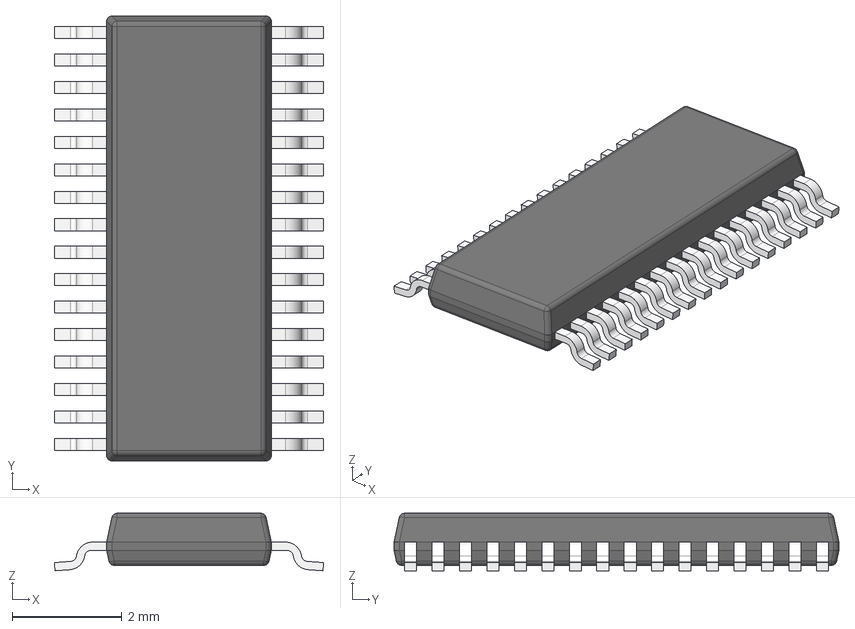
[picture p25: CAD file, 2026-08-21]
hw/Part Libraries/models/M0G3507QDGS32RQ1.stp
4.90 x 8.10 x 1.05 mm
BODY-VSSOP
LEAD-VSSOP x 32
PIN1

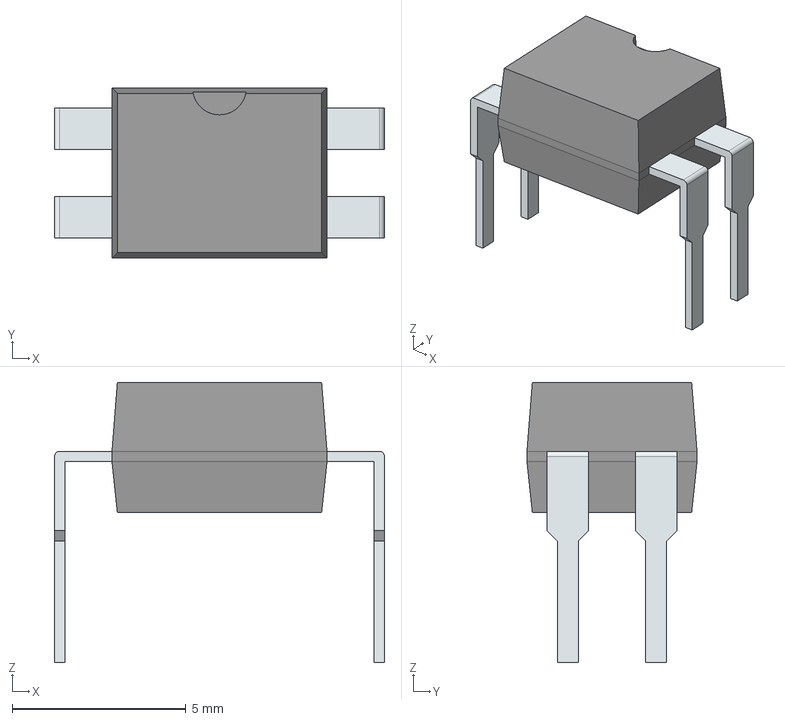
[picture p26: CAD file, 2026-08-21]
hw/Part Libraries/models/vishay_IRLD024PBF.stp
9.51 x 4.90 x 8.07 mm
PinsArrayLR

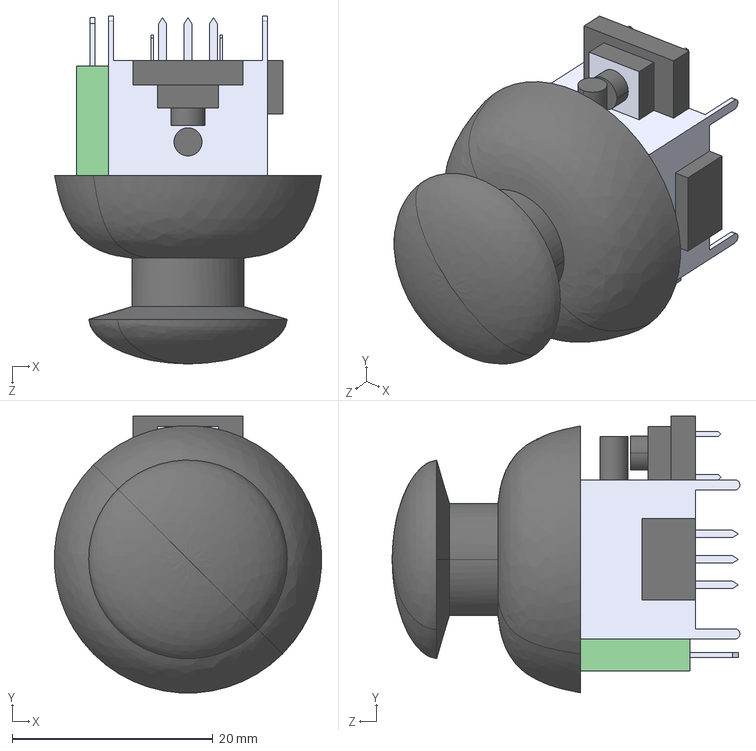
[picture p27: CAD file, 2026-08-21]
hw/Part Libraries/models/9032joystick.stp
26.6 x 27.6 x 34.7 mm

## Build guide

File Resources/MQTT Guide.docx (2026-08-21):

# Background

Wi-Fi is the name given to devices that communicate wirelessly employing the IEEE 802.11 standard. They typically operate in the 2.4 GHz Industrial-Scientific-Medical (ISM) unlicensed band that is shared with ZigBee (IEEE 802.15.4) and Bluetooth (IEEE 802.15.1) communications. The IEEE 802.11 standard describes how information is represented via radio frequency signals, i.e., the physical or PHY layer, and how communications are formatted and controlled, i.e., the media access control or MAC layer. Communication requirements beyond the PHY and MAC, e.g., flow control, error recovery, and routing, are handled at higher levels of the internet stack.

# Key Aspects of MQTT

MQTT (which originally stood for nothing (https://www.oasis-open.org/committees/download.php/49028/OASIS_MQTT_TC_minutes_25042013.pdf), but was backronymed to mean Message Queuing Telemetry Transport) is message passing mechanism that uses a centralized broker (server) to receive published data and send the data to any number of subscribers as shown below.

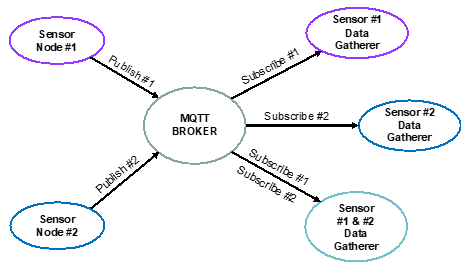
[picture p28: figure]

Figure 1: MQTT Publish-Subscribe Model

MQTT is a lightweight messaging protocol designed for low-bandwidth, high-latency, and unreliable networks. Developed in 1999 by IBM, MQTT is now a widely used open standard. MQTT is useful as it:

- Organizes data at the protocol level
- Coordinates actions between IOT devices
- Allows easy centralization of data to user-facing dashboards
- Sends connected clients only the data they need
- Can ensure a Quality Of Service (QOS) of data sent by clients
- Allows all clients to publish (broadcast) and subscribe (receive).
- Does not have the overhead of have addresses for clients like in email systems; since messages are not sent directly to clients, the client can be simplified.

Some key points about MQTT are:

- Clients become subscribers to “topic(s)” to get messages published to the broker about the “topic”
- Messages are published to a broker about a particular “topic”. In this Lab all topics MUST begin with your EID. A topic example is rg7677/b2w/hour where rg7677 is the student EID and b2w is a subtopic indicating that the message is from the LaunchPad board to the Web Application and the hour is a sub-subtopic that is current hour on the board.
- The job of an MQTT broker is to collect and sort messages based on the “topic”, so that the broker can distribute messages to subscribers of the “topic”.
- There is no direct connection between a publisher and subscriber.
- MQTT brokers do NOT normally store messages. All messages are sent via TCP which guarantees delivery (vs UDP).
- The publisher dictates the data format. The subscriber must know the format to decipher the data.

MQTT topology and the Publish/Subscribe Model:

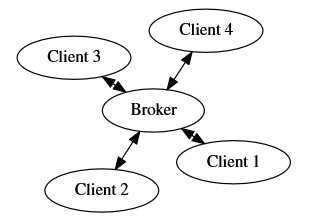
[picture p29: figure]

Figure 2 MQTT Client-Broker topology

MQTT includes ONLY broker to client/client to broker communications. MQTT networks have one broker which facilitates communication between many clients.

MQTT uses a Publish/Subscribe Model. In this model, data movement is controlled by topics. Clients decide what data they receive by deciding what topics they subscribe to. Clients can influence where data is sent by choosing what topic they attach to the data they publish. The messages sent and received always consist of a topic & data.

Although the broker is responsible for relaying data, it has no discretion to decide where data goes. The broker will relay a published message from any client to all clients that are subscribed to the topic of the message.

# Topic Naming scheme:

An MQTT topic is a hierarchical string identifier that categorizes messages being published/subscribed to within the MQTT system. Topics are represented as strings and are organized hierarchically using forward slashes (‘/’). For example, a topic could be

"sensors/temperature/EER/floor1/embeddedlab."

or

"EER/floor1/embeddedlab/temperature"

How topics are defined are up to you. As long as they follow the typical hierarchical format.

# Example of MQTT Communication

Here is an example of a typical MQTT communication between clients and how

the broker routes it.

1. An MQTT client publishes a message to a specific topic on the MQTT broker.
2. The MQTT broker receives the published message and examines the topic.
3. The broker checks its subscription database to determine which MQTT client have subscribed to that topic.
4. The broker forwards the message to all subscribed clients
5. Subscribed MQTT clients receive the message and can take action based on its content.

Now lets imagine a scenario where we have a IoT setup in the EER. We have three sensors which are their very own internet conected devices located in the EER. We have a temperature sensor in the 445L lab room, a thermostat located in the 319K room (let’s imagine the thermostat controls the A.C for the entirety of floor 1), and a faculty member has a mobile app that allows him to control the thermostat or see the readings from the sensors.

Here we have three clients:

- 445L Temperature Sensor
  - Can read temperature in the 445L room
- 319K Lab Thermostat
  - Connected via wire to the A.C, can control the A.C for the entirety of floor 1.
  - Has its own temperature sensor that allows it to read the temperature in the room it is in (the 319K lab in this case)
  - Has a temperature the thermostat can be set too. If the temperature
- in any of the rooms dip/rise above this temperature. The A.C is enabled to heat/cool
  - Has a mode for the A.C. The A.C can either be off, set to cool, or set to heat.
  - Can interface with external temperature sensors (such as the 445L temperature sensor)
  - This closely resembles popular IoT thermostats such as the Nest or Ecobee
- Mobile App
  - Allows you to control the thermostat (mode, set temperature)
  - Read the temperature readings across all temperature sensors

All of these clients are connected to one central server (The MQTT Broker) to facilitate communication. This server could be for examples McDermott MQTT server in his office, or a public/cloud based MQTT Server.

Figure 3 Client-Broker setup of the Example

Now lets try to analyze what information each client provides, and what information each client would want from another client.

- 445L Temperature Sensor
  - Reads the 445l lab room temperature, publishes it.
- 319K Lab Thermostat
  - Reads the temperature in the 319K room, can act on this reading (enable the A.C for floor 1). Can also publish it (for the mobile app)
  - Is interested in the temperature in the 445L room, can act on this reading (enable the A.C for floor 1)
  - Has a temperature that can be set to enable cooling/heat (acting on this data) It can publish this temperature (for the mobile app), and it can also have this changed externally (from the mobile app)
  - Has a A.C mode (off/cool/heat). It acts on this mode (enable the A.C for cool/hot if the outside temperature changes). It can publish this data (so the mobile app knows the current A.C mode), it can also have this changed externally (from the mobile app)
- Mobile App
  - Can set the A.C mode from the mobile app. Changes to this can be made from app or thermostat
  - Can set the thermostat temperature. Changes can be made from app or thermostat.
  - Can read all temperature sensor readings.

From this lets define the following topics, and these publishers and subscribers

- /EER/floor1/445Lab/temperature
  - Publishers:
    - 445L Temperature Sensor
  - Subscribers:
    - 319K Thermostat
    - Mobile App
- /EER/floor1/319KLab/temperature
  - Publishers:
    - 319K Thermostat
  - Subscribers:
    - Mobile App
- /EER/floor1/thermostat/set_temp
  - Publishers:
    - 319K Thermostat
    - Mobile App
  - Subscribers:
    - 319K Thermostat
    - Mobile App
- /EER/floor1/thermostat/mode
  - Publishers:
    - 319K Thermostat
    - Mobile App
  - Subscribers:
    - 319K Thermostat
    - Mobile App

# The scenario where 445L Lab Temp Changes

If the 445L lab room temperature changes. The sensor publishes to its topic.

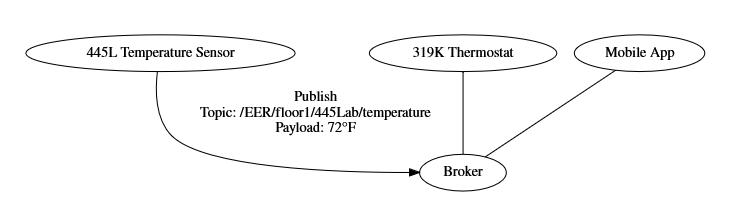
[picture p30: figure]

Figure 4: 445L Temperature Sensor publishes change

The thermostat and mobile app are subscribers, thus the broker forwards the message.

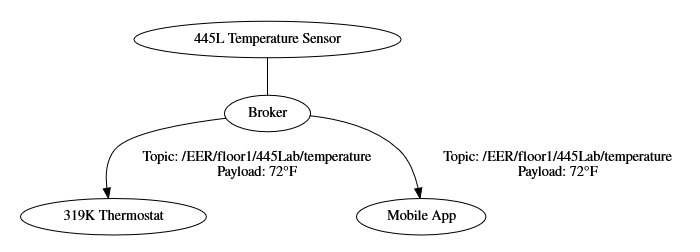
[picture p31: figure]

Figure 5: Subscribers are notified

# How to approach Lab 4

From the perspective of the lab we have a single broker and two clients:

- Your Alarm Clock
- The web dashboard

From the perspective of the free broker service however, it has your alarm clock and web dashboard as a client. As well as the alarm clock and web dashboard of everyone else in the class (and anyone else using the service). So when you define your topics make sure the topic string is unique. For example if everyone used the same topic, lets say “alarm/current_time”, you would be able to change the time of everyone’s alarm clock. So to make unique topic names, your topic should start with your eid, ex. “eid123/alarm/current_time”.

Here is how we reccomend approaching this lab to avoid stress and headaches. First things first, don’t try integrating lab3 right away, instead get topics working. Using the starter code, do the following:

1. ESP Bring up, the ESP8266 should be able to connect to a network and to the broker. This should be done in prep. Come to your TA’s if you were unable to do this.
2. Define your topics, and the subscriber/publisher relationships.
3. Have both of you open the web dashboard. Have one person subscribe to a topic, and have the other publish to the topic. The subscriber should be able to receive a message when this happens.
4. Modify your TM4C starter code so you can communicate with the ESP. The TM4C communicates with the ESP over UART. You can observe what is being sent to the ESP via USB-Serial between your PC and the TM4C using a serial terminal.
5. Test, can you publish to a topic from the TM4C, do you see this change reflected on the web dashboard?
6. Test, can you publish to a topic from the web dashboard, do you see this change reflected on the TM4C?
7. Now that you can publish/subscribe to topics. Now integrate your Lab 3 Code.

If you need any help, please email us or come to our office hours.

# Useful MQTT tutorials and projects:

- http://www.steves-internet-guide.com/mqtt-works/
- http://www.steves-internet-guide.com/download/mqtt-study-guide/
- http://www.steves-internet-guide.com/mqtt-protocol-messages-overview/
- http://www.steves-internet-guide.com/into-mqtt-python-client/
- http://www.steves-internet-guide.com/mqtt-websockets/
- http://www.steves-internet-guide.com/using-javascript-mqtt-client-websockets/
- http://www.steves-internet-guide.com/mosquitto-broker/
- http://www.steves-internet-guide.com/install-mosquitto-broker/
- http://www.steves-internet-guide.com/mqtt-broker-testing/
- http://www.steves-internet-guide.com/monitoring-mqtt-brokers/

2 MQTT Primer

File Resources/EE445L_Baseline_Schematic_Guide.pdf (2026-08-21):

# EE445L – Fall 2021

Lab Baseline Schematic Guide: Rev 10-1-2021 | Page 1

### McDermott & Valvano

This semester we have decided to standardize the I/O Pin assignment to make remote debugging a little

### bit easier for the TAs. The standardized Signal and Port assignments are listed below:

PORT | SIGNAL NAME | TM4C PORT ASSIGNMENT | NOTES
Port-A[2] | ST7735_SCK | SSI0_SCK | SSI interface to the ST7735 LCD
Port-A[3] | ST7735_TFT_CS | SSI0_SS
Port-A[4] | ST7735_MISO | SSI0_MISO
Port-A[5] | ST7735_MOSI | SSI0_MOSI
Port-A[6] | ST7735_DC | GPIO
Port-A[7] | ST7735_RST | GPIO
PORT | SIGNAL NAME | TM4C PORT ASSIGNMENT | NOTES
Port-B[0] | ST7735_CARD_CS | GPIO | ST7735 SDCARD Chip Select
Port-B[1] | PB1 | GPIO | Used for simple speaker
Port-B[2] | PB2 | GPIO/I2C0_SCK | Primarily GPIO, can be used for I2C
Port-B[3] | PB3 | GPIO/I2C0_SDA
Port-B[4] | TACH2 | T1_CCP0 | Tach Input for Lab-10
Port-B[5] | PB5 | GPIO/AIN_11 | GPIO or Analog input
Port-B[6] | PWM | M0_PWM0 | PWM control for Lab-10
Port-B[7] | PB7 | GPIO/PWM1
PORT | SIGNAL NAME | TM4C PORT ASSIGNMENT | NOTES
Port-C[4] | UP | GPIO | Used for switches in Lab 3
Port-C[5] | RIGHT | GPIO
Port-C[6] | LEFT | GPIO
Port-C[7] | DOWN | GPIO
PORT | SIGNAL NAME | TM4C PORT ASSIGNMENT | NOTES
Port-D[0] | SSI1_SCK | SSI1_SCK | SCK to TLV5616 DAC
Port-D[1] | SSI1_FS | SSI1_FS | SS/FS to TLV5616 DAC
Port-D[2] | PD2 | AIN_5 | Used to monitor DAC_OUT
Port-D[3] | SSI1_MOSI | SSI1_MOSI | MOSI to TLV5616 DAC
Port-D[6] | PD6 | GPIO | Can be used as alternate UART Port
Port-D[7] | PD7 | GPIO
PORT | SIGNAL NAME | TM4C PORT ASSIGNMENT | NOTES
Port-E[0] | 8266_GPIO_2 | GPIO | Status signal 8266 WiFi
Port-E[1] | RSTB_8266 | GPIO | Reset signal to 8266 WiFi
Port-E[2] | AIN_1 | AIN1 | Used for Audio Input Lab-9
Port-E[3] | GPIO | GPIO
Port-E[4] | 8266_TX 8266_RX | U5_RX U5_TX | UART TXD/RXD to 8266 WiFi Port-E[5]
PORT | SIGNAL NAME | TM4C PORT ASSIGNMENT | NOTES
Port-F[0] | LAUNCHPAD_SW2 | RESERVED for Launchpad | Mode Switch
Port-F[1] | RED_LED | | Red LED on LaunchPad
Port-F[2] | BLUE_LED | | Blue LED on LaunchPad
Port-F[3] | GREEN_LED | | Green LED on LaunchPad
Port-F[4] | LAUNCHPAD_SW1 | | Mode Switch
The baseline schematic printout is shown on the next two pages. Use this as the starting point for Eagle

### Schematics

Lab Baseline Schematic Guide: Rev 10-1-2021 | Page 2

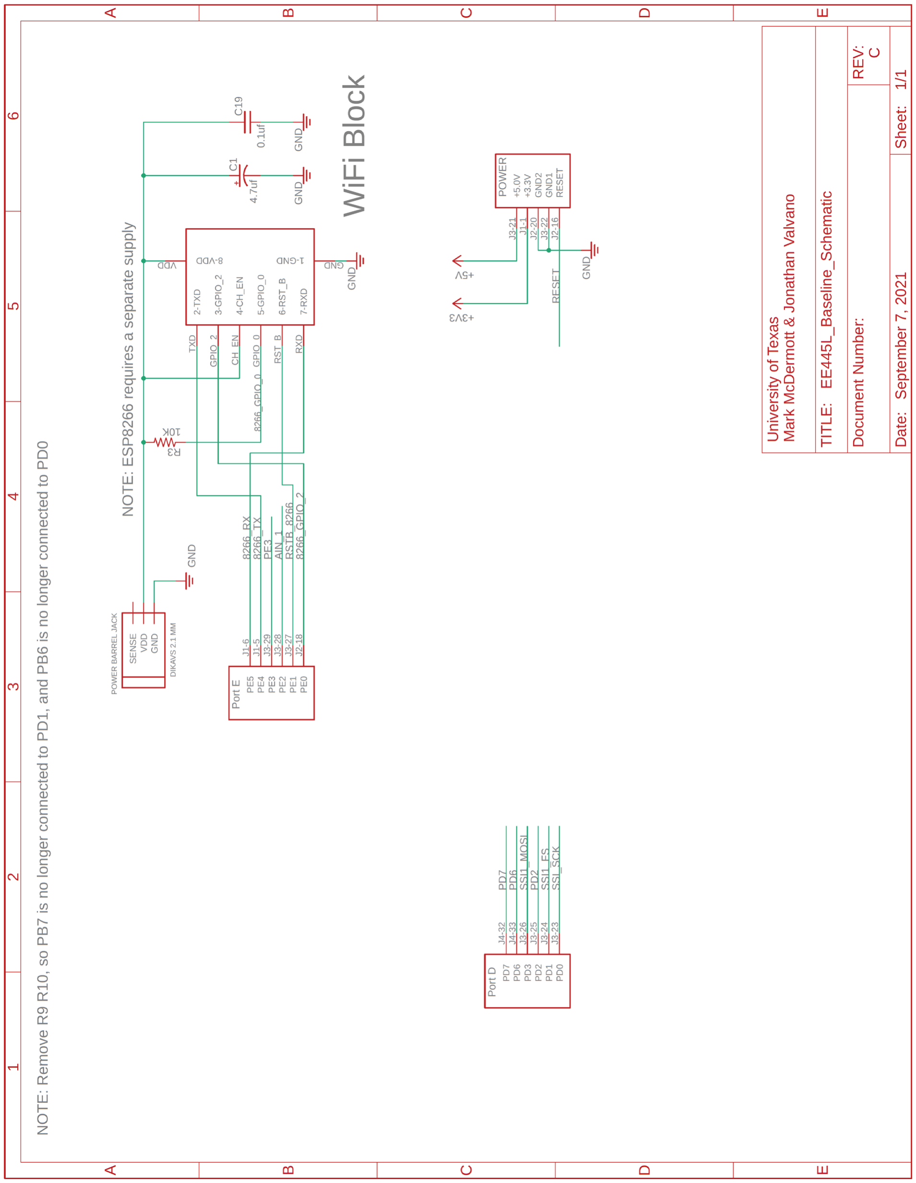
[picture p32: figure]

Lab Baseline Schematic Guide: Rev 10-1-2021 | Page 3

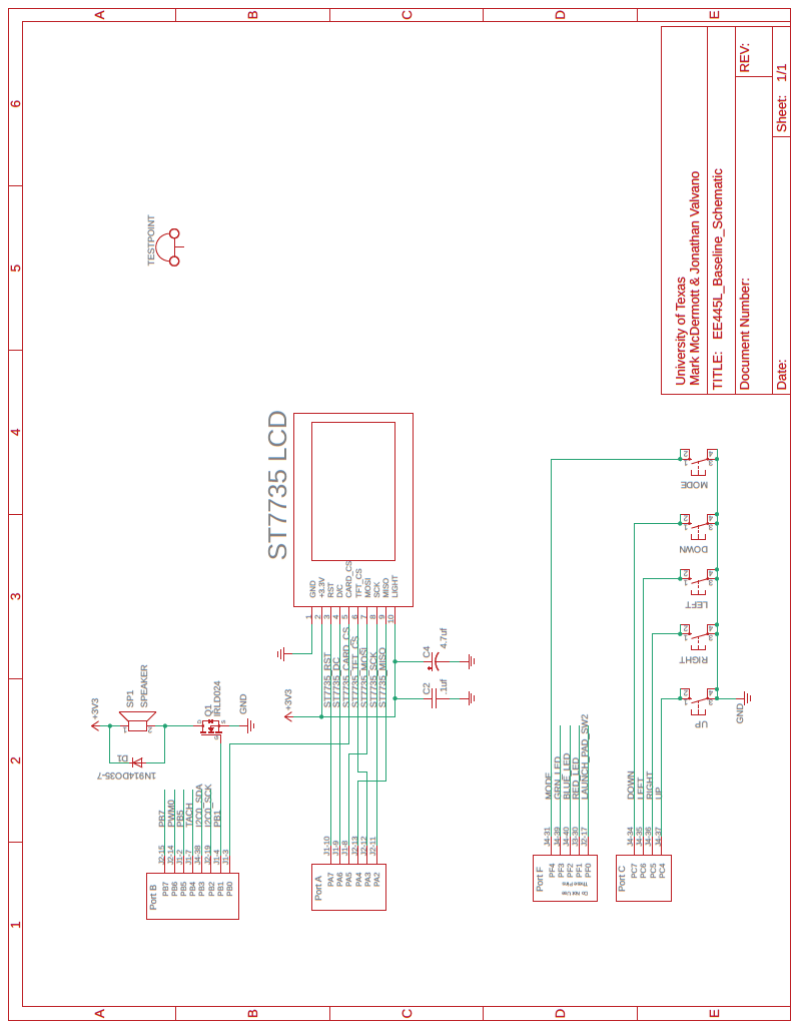
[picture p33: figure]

Lab Baseline Schematic Guide: Rev 10-1-2021 | Page 4

### PORT Initialization

Do not use this code without confirming that it does what you need it to do.

// ---------------------------------------------------------------------------//
// File name: Unified_Port_Init.c
//
// Author: | Mark McDermott
// Orig gen date: July 12, 2020
// Last update: August 17, 2020
//
// Description: This is the unified Port initialization routine 445L Labs
//
// Usage: | Call Lab_Brd_Port_Init () if you want to initialize all ports (preferred)
// | Call the individual port inits as needed.
//
// ---------------------------------------------------------------------------

#include "inc/tm4c123gh6pm.h"

#include "inc/Lab_Brd_Port_Init.h"

// --------------------------- | Port_Init | ------------------------------

void Lab_Brd_Port_Init(void){
Port_A_Init();
Port_B_Init();
Port_C_Init();
Port_D_Init();
Port_E_Init();
Port_F_Init();
}

// ----------------------------------------------------------------------------
// ---------------- | PORT A Initialization | --------------------------------
// ----------------------------------------------------------------------------//
// Port A drives the ST7735 LCD
//
// Backlight (pin 10) connected to +3.3 V
// MISO | (pin 9) connected to PA4
// SCK | (pin 8) connected to PA2 (SSI0Clk)
// MOSI | (pin 7) connected to PA5 (SSI0Tx)
// TFT_CS | (pin 6) connected to PA3 (SSI0Fss)
// CARD_CS | (pin 5) connected to PB0 (GPIO)
// Data/CMD (pin 4) connected to PA6 (GPIO)
// RESET | (pin 3) connected to PA7 (GPIO)
// VCC | (pin 2) connected to +3.3 V
// Gnd | (pin 1) connected to ground
//

void Port_A_Init(void){

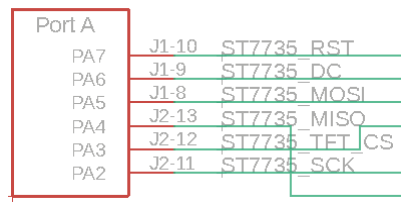
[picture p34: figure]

SYSCTL_RCGCSSI_R | |= 0x01; | // Activate SSI0
SYSCTL_RCGCGPIO_R | |= 0x01; | // Activate port A
while((SYSCTL_PRGPIO_R & 0x01)==0){}; | // allow time for clock to start
GPIO_PORTA_DIR_R | |= 0xC8; | // make PA3,6,7 out
GPIO_PORTA_AFSEL_R | &= ~0xC8; | // disable alt funct on PA3,6,7

Lab Baseline Schematic Guide: Rev 10-1-2021 | Page 5
GPIO_PORTA_DEN_R | |= 0xC8; | // enable digital I/O on PA3,6,7

// configure PA3,6,7 as GPIO
GPIO_PORTA_PCTL_R | = (GPIO_PORTA_PCTL_R
| & 0x00FF0FFF)
| + 0x00000000;
GPIO_PORTA_AMSEL_R | &= ~0xC8; | // disable analog functionality on PA3,6,7

// initialize SSI0
GPIO_PORTA_AFSEL_R | |= 0x2C; | // enable alt funct on PA2,3,5
GPIO_PORTA_DEN_R | |= 0x2C; | // enable digital I/O on PA2,3,5

// configure PA2,3,5 as SSI
GPIO_PORTA_PCTL_R | = (GPIO_PORTA_PCTL_R
| & 0xFF0F00FF)
| + 0x00202200;
GPIO_PORTA_AMSEL_R | &= ~0x2C; | // disable analog functionality on PA2,3,5
SSI0_CR1_R | &= ~SSI_CR1_SSE; | // disable SSI
SSI0_CR1_R | &= ~SSI_CR1_MS; | // master mode

// configure for system clock/PLL baud clock source
SSI0_CC_R | = (SSI0_CC_R&~SSI_CC_CS_M)
| + SSI_CC_CS_SYSPLL;

// clock divider for 8 MHz SSIClk (80 MHz PLL/24) // SysClk/(CPSDVSR*(1+SCR))
// 80/(10*(1+0)) = 8 MHz (slower than 4 MHz)
SSI0_CPSR_R | = (SSI0_CPSR_R
&~SSI_CPSR_CPSDVSR_M)
| + 10; | // must be even number

// SCR = 0 (8 Mbps data rate)
// SPH = 0
// SPO = 0
SSI0_CR0_R | &= ~(SSI_CR0_SCR_M
| | SSI_CR0_SPH
| | SSI_CR0_SPO);

// FRF = Freescale format
SSI0_CR0_R | = (SSI0_CR0_R
| &~SSI_CR0_FRF_M)
| + SSI_CR0_FRF_MOTO;

// DSS = 8-bit data
SSI0_CR0_R | = (SSI0_CR0_R
| &~SSI_CR0_DSS_M)
| + SSI_CR0_DSS_8;
// enable SSI
SSI0_CR1_R | |= SSI_CR1_SSE;

}

Lab Baseline Schematic Guide: Rev 10-1-2021 | Page 6

// ----------------------------------------------------------------------------
// ---------------- | PORT B Initialization | --------------------------------
// ----------------------------------------------------------------------------
//
// PB7 = GPIO/M0PWM1
// PB6 = PWM Output to Motor (M0PWM0)
// PB5 = GPIO/AIN11
// PB4 = Timer Capture input (TACH) // PB3 = GPIO/I2C_SDA
// PB2 = GPIO/I2C0_SCL
// PB1 = GPIO
// PB0 = ST7735 Card CS

void Port_B_Init(void){

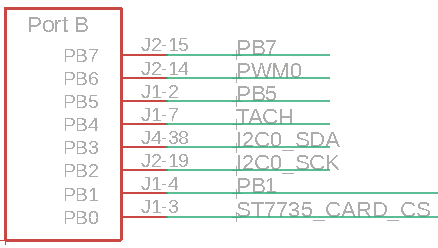
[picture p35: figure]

SYSCTL_RCGCPWM_R | |= 0x01; | // activate PWM0
SYSCTL_RCGCGPIO_R | |= 0x02; | // activate port B
while((SYSCTL_PRGPIO_R & 0x02) == 0){}; | // Wait

// --------------- Initialize PB7 as M0PWM1 -----------------------

GPIO_PORTB_AFSEL_R | |= 0x80; | // enable alt funct on PB7
GPIO_PORTB_PCTL_R | &= ~0xF0000000; | // configure PB7 as M0PWM1
GPIO_PORTB_PCTL_R | |= 0x40000000;
GPIO_PORTB_AMSEL_R | &= ~0x80; | // disable analog functionality on PB7
GPIO_PORTB_DEN_R | |= 0x80; | // enable digital I/O on PB7

// --------------- Initialize PB6 as M0PWM0 -----------------------
GPIO_PORTB_AFSEL_R | |= 0x40; | // enable alt funct on PB6
GPIO_PORTB_PCTL_R | &= ~0x0F000000; | // configure PB6 as PWM0
GPIO_PORTB_PCTL_R | |= 0x04000000;
GPIO_PORTB_AMSEL_R | &= ~0x40; | // disable analog functionality on PB6
GPIO_PORTB_DEN_R | |= 0x40; | // enable digital I/O on PB6

// --------------- Initialize PB5 as AIN11 -----------------------
GPIO_PORTB_DIR_R | &= ~0x20; | // make PB5 input
GPIO_PORTB_AFSEL_R | |= 0x20; | // enable alternate function on PB5
GPIO_PORTB_DEN_R | &= ~0x20; | // disable digital I/O on PB5
GPIO_PORTB_AMSEL_R | |= 0x20; | // enable analog functionality on PB5

// ----------------- Initialize PB4 as Timer Capture input (T1CCP0) ---------
GPIO_PORTB_DIR_R | &= ~0x10; | // make PB4 input
GPIO_PORTB_AFSEL_R | |= 0x10; | // enable alt funct on PB4
GPIO_PORTB_DEN_R | |= 0x10; | // enable digital I/O on PB4
| | // configure PB4 (T1CCP0)
GPIO_PORTB_PCTL_R | = (GPIO_PORTB_PCTL_R
| & 0xFFF0FFFF)
| + 0x00070000;
GPIO_PORTB_AMSEL_R | &= ~0x10; | // disable analog functionality on PB4

// ----------------- Initialize PB3-0 as GPIO ---------
GPIO_PORTB_PCTL_R | &= ~0x0000FFFF; | // GPIO
GPIO_PORTB_DIR_R | |= 0x0F; | // make PB3-0 out
GPIO_PORTB_AFSEL_R | &= ~0x0F; | // regular port function
GPIO_PORTB_DEN_R | |= 0x0F; | // enable digital I/O on PB3-0
GPIO_PORTB_AMSEL_R | &= ~0x0F; | // disable analog functionality on PB3-0
}

Lab Baseline Schematic Guide: Rev 10-1-2021 | Page 7

// ----------------------------------------------------------------------------
// ---------------- | PORT C Initialization | --------------------------------
// ----------------------------------------------------------------------------
//
// PC4 = UP switch
// PC5 = RIGHT switch
// PC6 = LEFT switch
// PC7 = DOWN switch
//

void Port_C_Init(void){

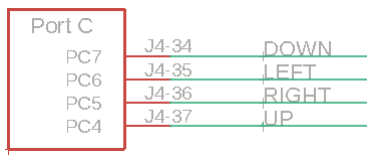
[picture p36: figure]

SYSCTL_RCGCGPIO_R | |= 0x04; | // Activate clock for Port C
while((SYSCTL_PRGPIO_R & 0x04) != 0x04){}; // Allow time for clock to start
GPIO_PORTC_PCTL_R | &= ~0xFFFF0000; | // regular GPIO
GPIO_PORTC_AMSEL_R | &= ~0xF0; | // disable analog function
GPIO_PORTC_DIR_R | &= ~0xF0; | // inputs on PC7-PC4
GPIO_PORTC_AFSEL_R | &= ~0xF0; | // regular port function
GPIO_PORTC_DEN_R | |= 0xF0; | // enable digital port
}

Lab Baseline Schematic Guide: Rev 10-1-2021 | Page 8

// ----------------------------------------------------------------------------
// ---------------- | PORT D Initialization | --------------------------------
// ----------------------------------------------------------------------------
//
// PD7 = GPIO/U2TX
// PD6 = GPIO/U2RX
// PD5 = Reserved for LaunchPad // PD4 = Reserved for Launchpad // PD3 = SSI1_MOSI (to TLV5616) // PD2 = AIN5
// PD1 = SSI1_FS/CS (to TLV5616) // PD0 = SSI1_SCK (to TLV5616)

void Port_D_Init(void){

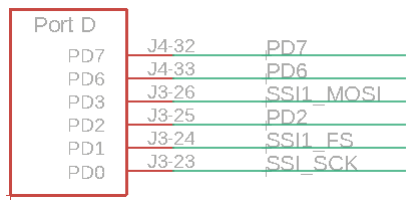
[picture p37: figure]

SYSCTL_RCGCGPIO_R | |= 0x08; | // activate port D
while((SYSCTL_PRGPIO_R & 0x08)==0){}; | // allow time for clock to stabilize

// --------------- Initialize PB7 as U2TX, PB6 as U2RX -----------------------

GPIO_PORTD_LOCK_R | = 0x4C4F434B; | // unlock REQUIRED for PD7
GPIO_PORTD_CR_R | |= 0xC0; | // commit PD6, PD7
GPIO_PORTD_AMSEL_R | &= ~0xC0; | // disable analog functionality on PD6, PD7
GPIO_PORTD_AFSEL_R | |= 0xC0; | // enable alternate function on PD6, PD7
GPIO_PORTD_DEN_R | |= 0xC0; | // enable digital on PD6, PD7 (PD6 is U2RX, PD7 is
U2TX)
GPIO_PORTD_PCTL_R =(GPIO_PORTD_PCTL_R
& 0x00FFFFFF)
| 0x11000000; // configure PD6, PD7 as UART

// --------------- Initialize PD2 as AIN5 ----------------------------------

GPIO_PORTD_DIR_R | &= ~0x04; | // make PD2 input
GPIO_PORTD_AFSEL_R | |= 0x04; | // enable alternate function on PD2
GPIO_PORTD_DEN_R | &= ~0x04; | // disable digital I/O on PD2
GPIO_PORTD_AMSEL_R | |= 0x04; | // enable analog functionality on PD2
// --------------- Initialize PD3,1,0 as SSI1 MOSI, FS & SCK ----------------
GPIO_PORTD_AMSEL_R | &= ~0x0B; | // disable analog functionality on PD
GPIO_PORTD_AFSEL_R | |= 0x0B; | // enable alt funct on PD3,1,0
GPIO_PORTD_DEN_R | |= 0x0B; | // enable digital I/O on PD3,1,0
GPIO_PORTD_PCTL_R | = (GPIO_PORTD_PCTL_R
& 0xFFFF0F00)
+ 0x00002022;
}

Lab Baseline Schematic Guide: Rev 10-1-2021 | Page 9

// ----------------------------------------------------------------------------
// ---------------- | PORT E Initialization | --------------------------------
// ----------------------------------------------------------------------------
//
// PE5 = 8266_RX (U5TX)
// PE4 = 8266_TX (U5RX)
// PE3 = GPIO
// PE2 = AIN_1 (Audio Input) // PE1 = 8266_8266
// PE0 = 8266_ GPIO_2

void Port_E_Init(void){

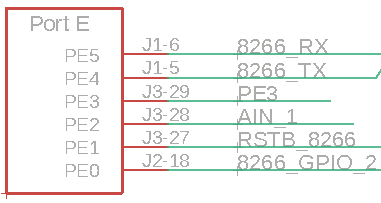
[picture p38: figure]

SYSCTL_RCGCGPIO_R | |= 0x10; | // activate port E
while((SYSCTL_PRGPIO_R & 0x10)==0){};

// --------------- Initialize PE5 as U5TX, PE4 as U5RX -----------------------

GPIO_PORTE_AFSEL_R | |= 0x30; | // enable alt funct on PE5-4
GPIO_PORTE_DEN_R | |= 0x30; | // enable digital I/O on PE5-4
| | // configure PE5-4 as UART
GPIO_PORTE_PCTL_R | = (GPIO_PORTE_PCTL_R
| & 0xFF00FFFF)
| + 0x00110000;
GPIO_PORTE_AMSEL_R | &= ~0x30; | // disable analog functionality on PE
// --------------- Initialize PE3,1,0 as GPIO ---------------------------------
GPIO_PORTE_DIR_R | |= 0x0A; | // output digital I/O on PE3,1
GPIO_PORTE_DIR_R | &= ~0x01; | // input digital I/O on PE0
GPIO_PORTE_AMSEL_R | &= ~0x0B; | // disable analog functionality on PE3,1,0
GPIO_PORTE_AFSEL_R | &= ~0x0B; | // disable alt funct on PE3,1,0
GPIO_PORTE_DEN_R | |= 0x0B; | // enable digital I/O on PE3,1,0
GPIO_PORTE_PCTL_R | = (GPIO_PORTE_PCTL_R
| & 0xFFFF0F00);
// --------------- Initialize PE2 as AIN1 ---------------------------------
GPIO_PORTE_DIR_R | &= ~0x04; | // make PE2 input
GPIO_PORTE_AFSEL_R | |= 0x04; | // enable alternate function on PE2
GPIO_PORTE_DEN_R | &= ~0x04; | // disable digital I/O on PE2
GPIO_PORTE_AMSEL_R | |= 0x04; | // enable analog functionality on PE2
}

Lab Baseline Schematic Guide: Rev 10-1-2021 | Page 10

// ----------------------------------------------------------------------------
// ---------------- | PORT F Initialization | --------------------------------
// ----------------------------------------------------------------------------//
// LaunchPad Pin Assignments
// PF4 = SW1
// PF3 = GREEN_LED
// PF2 = BLUE_LED
// PF1 = RED_LED
// PF0 = SW2

void Port_F_Init(void){

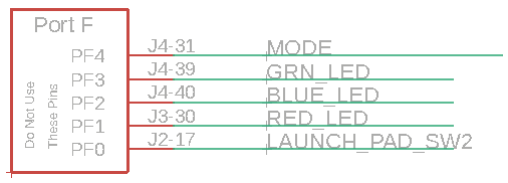
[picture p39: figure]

SYSCTL_RCGCGPIO_R | |= 0x00000020; | // activate clock for Port F
while((SYSCTL_PRGPIO_R & 0x20)==0){}; | // allow time for clock to stabilize
GPIO_PORTF_LOCK_R | = 0x4C4F434B; | // unlock GPIO Port F
GPIO_PORTF_CR_R | = 0x1F; | // allow changes to PF4-0
GPIO_PORTF_AMSEL_R | = 0x00; | // disable analog on PF
GPIO_PORTF_PCTL_R | = 0x00000000; | // PCTL GPIO on PF4-0
GPIO_PORTF_DIR_R | = 0x0E; | // PF4,PF0 in, PF3-1 out
GPIO_PORTF_AFSEL_R | = 0x00; | // disable alt function on PF7-0
GPIO_PORTF_PUR_R | = 0x11; | // enable pull-up on PF0 and PF4
GPIO_PORTF_DEN_R | = 0x1F; | // enable digital I/O on PF4-0
}

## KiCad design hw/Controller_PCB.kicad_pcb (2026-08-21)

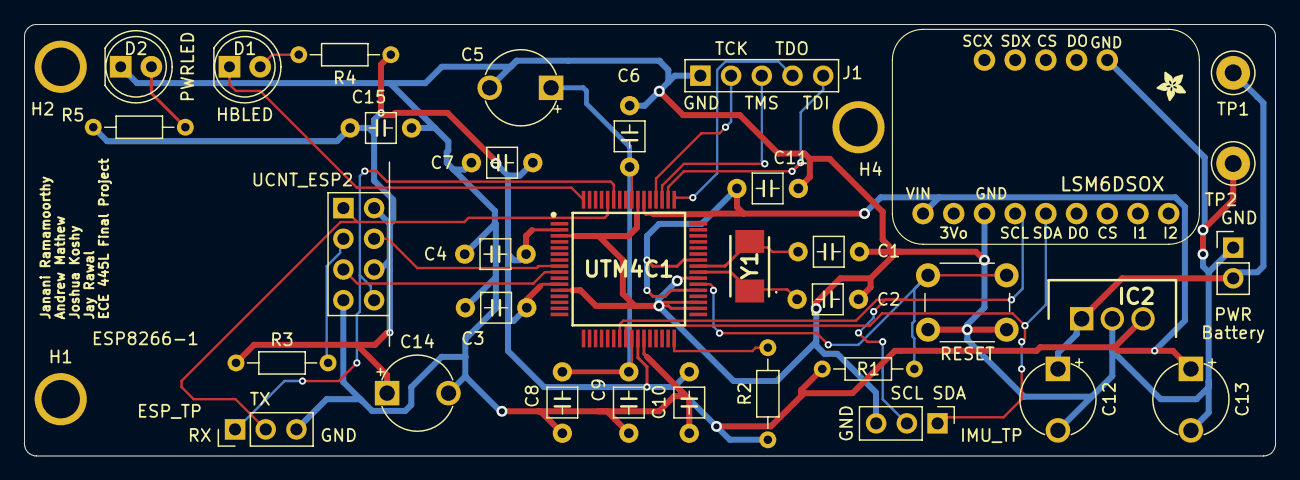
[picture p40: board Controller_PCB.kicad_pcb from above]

Board: 2 copper layers, 103.5 x 35.7 mm, 39 parts (0 on the bottom side), 22 nets.

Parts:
C1, C2: 10pF C0G; C_Axial_200mil
C3, C6, C7, C9: 0.1uF; C_Axial_200mil
C4, C10: 0.01uF; C_Axial_200mil
C5: 2.2uF; CP_Radial_Tantal200mil
C8, C11: 1uF; C_Axial_200mil
C12, C13: 4.7uF; CP_Radial_Tantal200mil
C14: 4.7 uf; CP_Radial_Tantal200mil
C15: 0.1 uf; C_Axial_200mil
D1: HBLED; LED_D5.0mm
D2: PWRLED; LED_D5.0mm
H1, H2, H4: MountingHole_4_40
IC2: LM2937ET-3.3_NOPB; TO254P470X1028X1955-3P
IMU_TP: Conn_01x03; PinHeader_1x03_P2.54mm_Vertical
J1: JTAG; PinHeader_1x05_P2.54mm_Vertical
J2: Battery; PinHeader_1x02_P2.54mm_Vertical
J3: Conn_01x03; PinHeader_1x03_P2.54mm_Vertical
JP1: 1X09_ROUND_70
JP2: 1X05_ROUND_70
R1, R3: 10k; R_Axial_DIN0204_L3.6mm_D1.6mm_P7.62mm_Horizontal
R2: 1M; R_Axial_DIN0204_L3.6mm_D1.6mm_P7.62mm_Horizontal
R4, R5: 220; R_Axial_DIN0204_L3.6mm_D1.6mm_P7.62mm_Horizontal
RESET: Reset; SW_PUSH_6mm
TP1: TP_BAT; TestPoint_Loop_D3.50mm_Drill1.4mm_Beaded
TP2: TP_GND; TestPoint_Loop_D3.50mm_Drill1.4mm_Beaded
U$9: ADAFRUIT_2.5MM
UCNT_ESP2: ESP8266-1; ESP8266_FemaleConnector
UTM4C1: TM4C123GH6PMIR; QFP50P1200X1200X160-64N
Y1: ABM3-16.000MHZ-B2-T; ABM3

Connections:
3V3CNT: C3.1, C4.1, C7.1, C10.1, C11.1, C13.1, C14.1, C15.1, IC2.3 (OUTPUT), JP1.1, R1.1, R2.1, R3.1, R4.1, R5.1, UCNT_ESP2.6 (Ch_PD), UCNT_ESP2.8 (Vcc), UTM4C1.2 (VDDA), UTM4C1.11 (VDD_1), UTM4C1.26 (VDD_2), UTM4C1.37 (VBAT), UTM4C1.42 (VDD_3), UTM4C1.54 (VDD_4)
/Lab7_microcontroller/LDO: C5.1, C6.1, C8.1, C9.1, UTM4C1.25 (VDDC_1), UTM4C1.56 (VDDC_2)
/Lab7_microcontroller/OSC1: C1.1, UTM4C1.41 (OSC1), Y1.2
/Lab7_microcontroller/OSC2: C2.1, UTM4C1.40 (OSC0), Y1.1
/Lab7_microcontroller/Reset: R1.2, RESET.2, UTM4C1.38 (~RST)
/Lab7_microcontroller/TCK: J1.2 (B), UTM4C1.52 (PC0/TCK/SWCLK)
/Lab7_microcontroller/TDI: J1.5 (C), UTM4C1.50 (PC2/TDI)
/Lab7_microcontroller/TDO: J1.4 (C), UTM4C1.49 (PC3/TDO/SWO)
/Lab7_microcontroller/TMS: J1.3 (C), UTM4C1.51 (PC1/TMS/SWDIO)
GND: C1.2, C2.2, C3.2, C4.2, C5.2, C6.2, C7.2, C8.2, C9.2, C10.2, C11.2, C12.2, C13.2, C14.2, C15.2, D2.1 (K), IC2.2 (GND), IMU_TP.3, J1.1 (A), J2.1 (A), J3.3, JP1.3, JP2.1, RESET.1, TP2.1, UCNT_ESP2.4 (GND), UTM4C1.3 (GNDA), UTM4C1.12 (GND_1), UTM4C1.27 (GND_2), UTM4C1.34 (XOSC0), UTM4C1.35 (GNDX), UTM4C1.39 (GND_3), UTM4C1.55 (GND_4)
unnamed: D1.2 (A), R4.2
unnamed: D2.2 (A), R5.2
unnamed: R3.2, UCNT_ESP2.2 (GPIO0)
unnamed: R2.2, UTM4C1.32 (~WAKE)
PA6: IMU_TP.2, JP1.4, UTM4C1.23 (PA6)
PA7: IMU_TP.1, JP1.5, UTM4C1.24 (PA7)
PD3: D1.1 (K), UTM4C1.64 (PD3)
PE0: UCNT_ESP2.3 (GPIO2), UTM4C1.9 (PE0)
PE1: UCNT_ESP2.7 (Reset), UTM4C1.8 (PE1)
PE4: J3.1, UCNT_ESP2.5 (TxD), UTM4C1.59 (PE4)
PE5: J3.2, UCNT_ESP2.1 (RxD), UTM4C1.60 (PE5)
V_BAT: C12.1, IC2.1 (INPUT), J2.2 (B), TP1.1

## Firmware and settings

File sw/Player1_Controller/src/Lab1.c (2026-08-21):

// ============================================================
// Lab1.c
// Just Dance IMU framework for TM4C123 + LSM6DSOX
//
// ============================================================
// HOW TO ADD A NEW MOVE  (read this, josh)
// ============================================================
// Everything about a move now lives in ONE place: the
// gMoveInfo[] table near the bottom of the "move registry"
// section. Each entry bundles:
//
//   - the Move_t enum value
//   - display name
//   - score function pointer
//   - per-move segment-engine tuning (thresholds, sample caps)
//
// Choreography is ONLY the ordered list in gChoreo[]. Total
// choreography period is computed automatically from the sum
// of step durations -- you do NOT edit a #define for that.
//
// Steps to add a brand-new move:
//   1. Add MOVE_YOURMOVE to the Move_t enum.
//   2. Write int32_t ScoreYourMove(const Segment_t *seg){...}
//      (forward-declare it above gMoveInfo[]).
//   3. Add one line to gMoveInfo[]:
//        { MOVE_YOURMOVE, "YOUR MOVE", ScoreYourMove, {..tuning..} }
//      Use DEFAULT_SEGMENT_TUNING if you want the global defaults.
//   4. Drop it into gChoreo[] wherever it should dance.
//
// To reorder existing moves: edit ONLY gChoreo[].
// To retune segmentation for one move: edit ONLY its row in
//   gMoveInfo[]. No more hunting through UpdateGestureEngine.
//
// ============================================================
// Original notes (preserved):
// Uses real hardware time from Timer0A at 16 MHz.
// Choreography timing is no longer affected by UART/I2C/processing delays.
//
// Timing behavior:
// - calibration sampling spans exactly 5000 ms
// - dance timeline starts exactly at calibration_start + 5000 ms
// - first move begins 10000 ms later
// - total from calibration start to first move = 15000 ms
//
// Logical mapping kept as:
//      IRL X = sensor Y
//      IRL Y = sensor Z
//      IRL Z = sensor X
// ----------------------------------------------------------------------------
#include <stdint.h>
#include <stdbool.h>
#include "PLL.h"
#include "../inc/tm4c123gh6pm.h"

#define CTRL3_C_SW_RESET   0x01
#define CTRL3_C_IF_INC     0x04
#define CTRL3_C_BDU        0x40
/* ============================================================
   Test / runtime mode
   Change only these lines for quick testing
   ============================================================ */
#define TEST_MODE_ENABLE                0
#define TEST_MODE_MOVE                MOVE_RIGHT_ARM_BEAT

#define ARC_ML_DATASET_MODE             0  //TURN ON TO f(s->energy >= startThresh DATA
#define ARC_ML_INFERENCE_ENABLE         1


#define PRINT_SEGMENT_SCORES   0   // set to 0 to disable

#define PRINT_INDIVIDUAL_SEGMENT_SCORES   0   // easy to comment out //ADD THIS BACK


#define TEST_STREAM_PRINT_ENABLE        0
#define CHOREO_STREAM_PRINT_ENABLE      0
#define STREAM_PRINT_DIVIDER            20

/* ARC ML detect confidence display only.
   scoreOut for ARC ML is still "logit * 1000" */
#define ARC_ML_STRONG_LOGIT_MILLI       1200

/* ============================================================
   LSM6DSOX registers
   ============================================================ */
#define LSM6DSOX_ADDR       0x6A

#define WHO_AM_I            0x0F
#define CTRL1_XL            0x10
#define CTRL2_G             0x11
#define CTRL3_C             0x12
#define STATUS_REG          0x1E

#define OUTX_L_G            0x22
#define OUTX_L_A            0x28

/* ============================================================
   LED definitions
   ============================================================ */
#define LED_RED   0x02
#define LED_BLUE  0x04
#define LED_GREEN 0x08

/* ============================================================
   Real timing
   ============================================================ */
#define TIMER_TICKS_PER_MS              16000U   // 16 MHz

#define CALIBRATION_MS                  5000U
#define CALIBRATION_SAMPLE_PERIOD_MS    10U
#define MAIN_SAMPLE_PERIOD_MS           5U

/* ============================================================
   Choreography timing

   CHOREO_PERIOD_MS is computed at startup from gChoreo[] sum.
   You do NOT need to edit it when you add/remove steps.
   ============================================================ */
#define WINDOW_GRACE_MS                 450U

/* ============================================================
   Filter constants
   ============================================================ */
#define GYRO_LPF_SHIFT              2   // 1/4
#define ACCEL_LPF_SHIFT             3   // 1/8
#define GRAVITY_LPF_SHIFT           5   // 1/32
#define BIAS_LPF_SHIFT              5   // 1/32

/* ============================================================
   Stillness / bias update
   ============================================================ */
#define STILL_GYRO_MAG_THRESH       2400
#define STILL_ACCEL_DYN_THRESH      1600
#define STILL_COUNT_FOR_BIAS        20

/* ============================================================
   DEFAULT segment detection tuning

   These are the baseline thresholds used when a move does not
   override them. Per-move overrides live in gMoveInfo[].

   to start a motion, energy must exceed START_ENERGY_THRESH
   once already in motion, the segment stays alive until energy stays low enough
   if energy is low for QUIET_END_COUNT quiet counts, the segment ends
   segment must have at least SEGMENT_MIN_SAMPLES samples to count
   segment is forced to end at SEGMENT_MAX_SAMPLES max
   after ending, wait SEGMENT_COOLDOWN_MS ms before another segment can start
   ============================================================ */
#define START_ENERGY_THRESH         5400

#define CONTINUE_ENERGY_THRESH      2600
#define QUIET_END_COUNT             8
#define SEGMENT_MIN_SAMPLES         8

#define SEGMENT_MAX_SAMPLES         140
#define SEGMENT_COOLDOWN_MS         90

/* ============================================================
   Gesture scoring thresholds for rule-based moves
   ============================================================ */
#define SCORE_ACCEPT_THRESH         62
#define SCORE_STRONG_THRESH         84

#define DOMINANCE_NUM               10


/* ============================================================
   EEPROM-backed song selection
   Persists across TM4C reset button presses
   ============================================================ */
#define SONG_ID_DEFAULT         0U
#define SONG_ID_EEPROM_BLOCK    0U
#define SONG_ID_EEPROM_OFFSET   0U


/* ============================================================
   Right Arm Flex fixed-point NN model (16 -> 3 -> 1)
   NOTE: Python export was mislabeled as ARC, but these values
   are for MOVE_RIGHT_ARM_FLEX.
   ============================================================ */
#define RIGHT_ARM_FLEX_NN_INPUTS 16
#define RIGHT_ARM_FLEX_NN_HIDDEN 3
#define RIGHT_ARM_FLEX_NN_SCALE 1000

static const int64_t gRightArmFlexNnInputMeanScaled[16] = {
    -11905076, 397134943, 20038516, -1515115,
    15307987, 2019318, 402904567, 121889185,
    1299943, 845283752, -126318, 10389962,
    4571592, 6115, 18350, 1146
};

static const int32_t gRightArmFlexNnInputStdScaled[16] = {
    8438320, 189283995, 8305647, 10289860,
    8978951, 2342004, 284174002, 86004163,
    1262965, 371312594, 707671, 8413284,
    4213123, 35029, 21843, 1363
};

static const int32_t gRightArmFlexNnW1Scaled[16][3] = {
    { -1738,  276, -1429 },
    { -2524,  893,  -691 },
    { -1025, -1056, -663 },
    {  -775,  318,  -735 },
    { -1542, 2694,  1356 },
    {    52, -2692,  492 },
    {  -695, -1542, 1992 },
    {  -652, -1270, 2622 },
    {    61, -1855,  372 },
    {  -111, -1838, -493 },
    {   573,  -755, -322 },
    {   752,   313,  303 },
    {  3727,  2052,  876 },
    {     2,  -319,  516 },
    { -1726,  -953, -166 },
    { -1739,  -885, -252 }
};

static const int32_t gRightArmFlexNnB1Scaled[3] = { 3028, 192, -4220 };
static const int32_t gRightArmFlexNnW2Scaled[3] = { -5233, 5581, 5169 };
static const int32_t gRightArmFlexNnB2Scaled = -9527;
/* ============================================================
   ARC fixed-point NN model
   16 -> 3 -> 1, ReLU
   All values scaled by 1000.
   ============================================================ */
#define ARC_ML_FEATURE_COUNT        16
#define ARC_NN_INPUTS               16
#define ARC_NN_HIDDEN               3
#define ARC_NN_SCALE                1000

static const int64_t gArcNnInputMeanScaled[16] = { -4286045, 937880970, 23307576, 2960621, 21887939, 1207515, 484150636, 333695545, 372212, 2296309970, 73303, 7246667, 11352697, 19833, 31439, 4364 };

static const int32_t gArcNnInputStdScaled[16] = { 6789393, 345507439, 6554921, 6455742, 7540062, 1179725, 216339271, 153058171, 446443, 696415312, 267038, 5313862, 5347241, 41326, 20291, 2869 };

static const int32_t gArcNnW1Scaled[16][3] = {
    { -450,  346,  296 },
    { -913, 1341,  828 },
    { -122,  350,  160 },
    { -252,  215,  294 },
    {  205, -151,  -75 },
    {  507, -826, -456 },
    { -925,  698,  428 },
    { -663,  701,  713 },
    {  142, -513, -268 },
    {  289, -440, -246 },
    { -206,   48,  108 },
    {  283,  -60, -196 },
    { -416,  445,  488 },
    { -500,  163,  276 },
    {  -24, -225,  -47 },
    {  -33,  -44,  -41 }
};

static const int32_t gArcNnB1Scaled[3] = { 1359, 1411, 1427 };
static const int32_t gArcNnW2Scaled[3] = { -1512, 2407, 1534 };
static const int32_t gArcNnB2Scaled = -3410;

/* ============================================================
   Bent Arm Sway fixed-point NN model (16 -> 3 -> 1)
   ============================================================ */
#define SWAY_NN_INPUTS 16
#define SWAY_NN_HIDDEN 3
#define SWAY_NN_SCALE 1000

static const int32_t gSwayNnInputMeanScaled[16] = { 631579, 5446881, 8527537, 130519, 563302, 400102, 10752218, 6931126, 1479982, 703319, 30596, 6358372, 35628, 4568, 11896323, 1192053 };

static const int32_t gSwayNnInputStdScaled[16] = { 482376, 5216440, 5968406, 6396197, 321760, 293032, 6208636, 5269852, 5478226, 1073164, 515636, 3710559, 16712, 2595, 3992309, 1952465 };

static const int32_t gSwayNnW1Scaled[16][3] = {
    { 197, -19, 732 },
    { 271, 1955, 1560 },
    { 193, 150, 1592 },
    { 395, 915, 2368 },
    { 265, -323, 1462 },
    { 176, 92, 1058 },
    { 47, -2002, 179 },
    { -197, 599, -919 },
    { -79, 216, -411 },
    { -204, 34, -1318 },
    { 343, 439, 1909 },
    { -158, 294, -1437 },
    { 53, -699, 316 },
    { 62, -326, 271 },
    { 98, 216, 748 },
    { -7, -395, -150 }
};

static const int32_t gSwayNnB1Scaled[3] = { -41, -2154, -424 };
static const int32_t gSwayNnW2Scaled[3] = { 806, -3299, 4827 };
static const int32_t gSwayNnB2Scaled = -9809;

/* ============================================================
   Right Arm Wave fixed-point NN model (16 -> 3 -> 1)
   ============================================================ */
#define RIGHT_ARM_WAVE_NN_INPUTS 16
#define RIGHT_ARM_WAVE_NN_HIDDEN 3
#define RIGHT_ARM_WAVE_NN_SCALE 1000

static const int64_t gRightArmWaveNnInputMeanScaled[16] = {
    -5643873, 124021500, 4660091, 28718,
    5246445, 7595400, 100577700, 38666273,
    11214418, 240206573, 68573, 5672591,
    1366373, 46809, 3800, 309
};
/* ============================================================
   Right Arm Throw fixed-point NN model (16 -> 3 -> 1)
   NOTE: Python export was mislabeled as ARC, but these values
   are for MOVE_RIGHT_ARM_THROW.
   ============================================================ */
#define RIGHT_ARM_THROW_NN_INPUTS 16
#define RIGHT_ARM_THROW_NN_HIDDEN 3
#define RIGHT_ARM_THROW_NN_SCALE 1000

static const int64_t gRightArmThrowNnInputMeanScaled[16] = {
    -15414085, 178266101, 19887279, -5452488,
    11137403, 2181031, 186574860, 35907868,
    2306512, 617245775, -153264, 9961597,
    2201899, 40078, 12597, 504
};

/* ============================================================
   Right Arm Tall Scoop fixed-point NN model (16 -> 3 -> 1)
   NOTE: Python export was mislabeled as ARC, but these values
   are for MOVE_RIGHT_ARM_TALL_SCOOP.
   ============================================================ */
#define RIGHT_ARM_TALL_SCOOP_NN_INPUTS 16
#define RIGHT_ARM_TALL_SCOOP_NN_HIDDEN 3
#define RIGHT_ARM_TALL_SCOOP_NN_SCALE 1000

static const int64_t gRightArmTallScoopNnInputMeanScaled[16] = {
    -10894092, 374115626, 20586755, -868902,
    11934098, 1144650, 313671847, 116686117,
    1118098, 1190514540, 25552, 10025190,
    4978896, 60485, 8374, 644
};

static const int32_t gRightArmTallScoopNnInputStdScaled[16] = {
    11890892, 162014713, 6497215, 13903109,
    9413162, 1285931, 228504758, 85003758,
    1589565, 377046119, 784729, 8890628,
    5093632, 174839, 13407, 1031
};

static const int32_t gRightArmTallScoopNnW1Scaled[16][3] = {
    { -1313, 1347, -2130 },
    { -3904, -953, -3642 },
    { -2482, -865, -1314 },
    { -2715,  974, -1106 },
    { -1662, -2436, 2070 },
    { 1938, -4459, 2284 },
    { -1223, -1181,  753 },
    { -1151, -1176, 1017 },
    { 2548, 1465, 3795 },
    { -1503, -816,  -97 },
    { 3959, -2863, 3599 },
    { -2586,  -49,  551 },
    {  226, -1305, -2844 },
    { 1479, 3026, -868 },
    { 1621,  283,  291 },
    { 1565,  496,   47 }
};

static const int32_t gRightArmTallScoopNnB1Scaled[3] = { 1333, 868, 1113 };
static const int32_t gRightArmTallScoopNnW2Scaled[3] = { -8816, 6318, 7162 };
static const int32_t gRightArmTallScoopNnB2Scaled = -7547;
static const int32_t gRightArmThrowNnInputStdScaled[16] = {
    13491974, 109059461, 9193605, 12504597,
    8800294, 3061622, 141498832, 27190841,
    3226915, 270453709, 801525, 5169331,
    3479157, 145091, 16212, 648
};

static const int32_t gRightArmThrowNnW1Scaled[16][3] = {
    {  544, -868, -1253 },
    { -1012, -195,  -678 },
    {  873,  777,  -980 },
    {  186, -882, -1433 },
    { -2428, -460, 1493 },
    {  720, -1113, -748 },
    { -402,  757,  -622 },
    { -355,  771,  -464 },
    {  370, -515,  -918 },
    { 1528,  879, -1047 },
    {  634,   38,  -770 },
    { -1038, -283, -510 },
    {   68,   -1,  -436 },
    {  -12,   45,   -52 },
    { -651,  306,  -241 },
    { -653,  396,  -285 }
};

static const int32_t gRightArmThrowNnB1Scaled[3] = { 1871, -1196, -533 };
static const int32_t gRightArmThrowNnW2Scaled[3] = { -3552, 2644, 3362 };
static const int32_t gRightArmThrowNnB2Scaled = -5864;

/* ============================================================
   Flex Throw Hands fixed-point NN model (16 -> 3 -> 1)
   NOTE: Python export was mislabeled as ARC, but these values
   are for MOVE_FLEX_THROW_HANDS.
   ============================================================ */
#define FLEX_THROW_HANDS_NN_INPUTS 16
#define FLEX_THROW_HANDS_NN_HIDDEN 3
#define FLEX_THROW_HANDS_NN_SCALE 1000

static const int64_t gFlexThrowHandsNnInputMeanScaled[16] = {
    -17705541, 319374856, 21642342, -8536477,
    8927081, 1027577, 326410063, 84712874,
    1585910, 863936595, -290342, 9169063,
    3821658, 33793, 19063, 1009
};

static const int32_t gFlexThrowHandsNnInputStdScaled[16] = {
    13362690, 183629229, 9353837, 14728798,
    7892666, 1383379, 273709261, 75192830,
    4705605, 480386855, 754540, 7758600,
    4993876, 136125, 20419, 1070
};

static const int32_t gFlexThrowHandsNnW1Scaled[16][3] = {
    {  548, -442, -1062 },
    {  284, -750, -1437 },
    {  -57, 1131, 2104 },
    {  626, -436, -1357 },
    { 1245, -504, -677 },
    { 1248,  489,  990 },
    { -482,   23,  247 },
    {  140, -812, -1659 },
    {  863, -423, -894 },
    {  777, -778, -1867 },
    { -732,  -45,  167 },
    {  333, -260, -906 },
    { 1263,  156,  747 },
    {  366, -209, -401 },
    {  -80,  -83,   80 },
    {  289, -238, -734 }
};

static const int32_t gFlexThrowHandsNnB1Scaled[3] = { 3480, -272, -420 };
static const int32_t gFlexThrowHandsNnW2Scaled[3] = { -3075, 2149, 4503 };
static const int32_t gFlexThrowHandsNnB2Scaled = -3416;

static const int32_t gRightArmWaveNnInputStdScaled[16] = {
    4264131, 140086693, 4741404, 3109053,
    3664957, 14333050, 190194217, 75137836,
    24875734, 290425500, 665988, 4655677,
    2143262, 206754, 10522, 850
};

static const int32_t gRightArmWaveNnW1Scaled[16][3] = {
    {  677, -431, -822 },
    { -777,  210,  178 },
    {  -47,  -10, -413 },
    {  385, -309, -278 },
    { -1360, 736, 1855 },
    { -136,   85,   75 },
    {    3, -675, -953 },
    {   -7, -653, -932 },
    {  144, -210, -234 },
    {  245, -368, -483 },
    { -164,  131,  324 },
    { -572,  505,  546 },
    {   87,  -66,  148 },
    {   -7,  -20,  -11 },
    {  114, -222, -134 },
    {   91,  -14, -200 }
};

static const int32_t gRightArmWaveNnB1Scaled[3] = { 2963, 112, -249 };
static const int32_t gRightArmWaveNnW2Scaled[3] = { -1994, 1688, 2739 };
static const int32_t gRightArmWaveNnB2Scaled = -5273;


void Clock_Init16MHz_MOSC(void){
    SYSCTL_RCC2_R |= 0x80000000;          // USERCC2
    SYSCTL_RCC2_R |= 0x00000800;          // BYPASS2

    SYSCTL_RCC_R &= ~0x00000030;          // clear OSCSRC
    SYSCTL_RCC2_R &= ~0x00000070;         // clear OSCSRC2
                                              // both select MOSC = 0

    SYSCTL_RCC_R = (SYSCTL_RCC_R & ~0x000007C0) | 0x00000540; // 16 MHz crystal

    SYSCTL_RCC_R &= ~0x00400000;          // no system divider
    SYSCTL_RCC2_R |= 0x00002000;          // power down PLL

    volatile uint32_t delay;
    delay = SYSCTL_RCC_R;
    delay = SYSCTL_RCC_R;
    delay = SYSCTL_RCC_R;
    (void)delay;
}
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
int main(void){
    int16_t ax, ay, az, gx, gy, gz;
    ProcSample_t s;
    Move_t expected, detected;
    int32_t score;
    uint32_t printCount = 0;
    uint32_t calibrationStartMs = 0;
    uint32_t nextMainSampleMs;
    uint32_t nowMs;
    bool runStarted = false;

    Clock_Init16MHz_MOSC();
    LED_Init();
    PD3_Init();
    PD3_On();
    LED_Set(LED_BLUE);

    Timer0A_InitFreeRunning();
    UART0_Init();
    UART5_Init();
	UART5_FlushRx();
    I2C1_Init();

    EEPROM_Init();
    LoadSongIDFromEEPROM();
    gChoreoPeriodMs = ComputeChoreoPeriodMs();

    UART0_OutString("LSM6DSOX Just Dance framework starting\r\n");
    UART0_OutString("Boot song ID: ");
    UART0_OutUDec(activeSongID);
    UART0_OutString("\r\n");

bool ok = false;

while(!ok){
    for(int i = 0; i < 5; i++){
        I2C1_Init();

        uint32_t t = TimeNowMs();
        WaitUntilMs(t + 20);

        if(LSM6DSOX_Init()){
            ok = true;
            break;
        }
    }

    if(!ok){
        UART0_OutString("Sensor init failed, retrying...\r\n");
        LED_Set(LED_BLUE);

        uint32_t t = TimeNowMs();
        WaitUntilMs(t + 100);   // small retry delay
    }
}

    UART0_OutString("Idle. Send '0', '1', or '2' to choose song, send 's' to start.\r\n");

    while(1){

        if(!runStarted){
            if(HandleUARTCommandsAndCheckStart()){
                UART0_OutString("Start command received\r\n");
                UART0_OutString("Calibrating for 5 seconds in handheld start pose.\r\n");

                if(!Calibrate(&calibrationStartMs)){
                    UART0_OutString("Calibration failed\r\n");
                    LED_Set(LED_BLUE);
                    while(1){}
                }

                gDanceStartMs = calibrationStartMs + CALIBRATION_MS;

                UART0_OutString("Calibration done\r\n");
								PrintDetectRow(MOVE_WAIT, 69);
                PrintRuntimeBanner();

                if(!TEST_MODE_ENABLE){
                    UART0_OutString("Schedule: CAL 5.0, WAIT 10.5, PUMP DOWN 3.5, ARC 1.5, CROSS ARMS 2.0, PUMP DOWN 3.5, ARC 1.5, CROSS ARMS 2.8, SWAY x6 (5.4), KICK 1.9, SWAY x6 (5.4), KICK 1.7\r\n");
                }

#if ARC_ML_DATASET_MODE
                PrintArcDatasetHeader();
#endif

                LED_Set(LED_GREEN);

                gLastPrintedStepIndex = 0xFFFFFFFFU;
                StepScore_Reset();
                nextMainSampleMs = gDanceStartMs + MAIN_SAMPLE_PERIOD_MS;
                printCount = 0;
                runStarted = true;
            }

            continue;
        }

        AdvanceToNextSample(&nextMainSampleMs, MAIN_SAMPLE_PERIOD_MS);
        (void)HandleUARTCommandsAndCheckStart();   // keep accepting song changes for next run

        nowMs = TimeNowMs();

        /* Handle one-shot step-final detect emission on step boundaries */
        StepScore_HandleBoundary(nowMs);

        if(ReadRaw(&ax, &ay, &az, &gx, &gy, &gz)){
            BuildProcessedSample(ax, ay, az, gx, gy, gz, &s);

            detected = UpdateGestureEngine(&s, &expected, &score);
            nowMs = TimeNowMs();

            PrintStepChangeIfNeeded(nowMs);

#if TEST_STREAM_PRINT_ENABLE
            if(TEST_MODE_ENABLE){
                printCount++;
                if(printCount >= STREAM_PRINT_DIVIDER){
                    PrintReadingLogicalProcessed(&s, expected);
                    printCount = 0;
                }
            }else
#endif
#if CHOREO_STREAM_PRINT_ENABLE
            {
                printCount++;
                if(printCount >= STREAM_PRINT_DIVIDER){
                    UART0_OutString("[E] ");
                    UART0_OutSDec(s.energy);
                    UART0_OutString(" | EXP:");
                    UART0_OutString(MoveName(expected));
                    UART0_OutString("\r\n");
                    printCount = 0;
                }
            }
#else
            {
                (void)printCount;
            }
#endif

            if(detected != MOVE_NONE){
                UART0_OutString("[DETECT] t=");
                PrintDanceTimeMs(nowMs);
                UART0_OutString("s | MOVE: ");
                UART0_OutString(MoveName(detected));
                UART0_OutString(" | SCORE: ");
                UART0_OutSDec(score);
                UART0_OutString("\r\n");
            }
        }
    }
}

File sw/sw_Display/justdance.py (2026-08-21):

import tkinter as tk
from tkinter import font
import cv2
from PIL import Image, ImageTk
import serial
import threading
import time
import os
import random
import math

SERIAL_PORT = 'COM11' # Make sure this matches your Hub's COM port!
BAUD_RATE = 115200

# Dictionary of your videos
VIDEOS = {'G': "gangnamfinal.mp4", 'P': "partyfinal.mp4"}

# Define exactly when (in seconds) the score screen should pop up for each video.
SCORE_TIMES = {'G': 98.0, 'P': 85.0} 

MAX_SCORE = 5300  # Updated Max Score

# ==========================================
# --- NEW VARIABLES TO MESS WITH ---
# ==========================================

# Start the video at a specific point in time (in milliseconds)
# e.g., 10000 = start 10 seconds into the video.
VIDEO_START_OFFSET_MS = 0 

# ==========================================

class JustDanceGUI:
    def __init__(self, root):
        self.root = root
        self.root.title("Just Dance Sync Hub")
        self.root.geometry("1280x720")
        self.root.configure(bg='black')

        self.p1_total_score = 0
        self.p2_total_score = 0
        self.p1_timer = None
        self.p2_timer = None
        self.start_time = None
  
        self.current_frame = 0
        
        self.current_end_time = 9999.0
        self.score_shown = False
        
        # Calibration state flags (Independent now)
        self.p1_calibrating = False
        self.p2_calibrating = False
        self.flash_color_state = False

        # --- Layout ---
  
        self.video_frame = tk.Frame(self.root, bg='black')
        self.video_frame.place(relx=0, rely=0, relwidth=1.0, relheight=1.0)
        
        self.left_sidebar_frame = tk.Frame(self.root, bg='#1a1a1a')
        self.right_sidebar_frame = tk.Frame(self.root, bg='#1a1a1a')

        # --- Video Canvas ---
        self.video_label = tk.Label(self.video_frame, bg='black')
        self.video_label.pack(expand=True, fill="both")
        self.cap = None
        
        self.video_running = False

        # --- End Screen Overlay ---
        self.end_frame = tk.Frame(self.video_frame, bg='#161625', bd=8, relief=tk.RIDGE)
        
        self.end_title = tk.Label(self.end_frame, text="🎵 DANCE COMPLETE! 🎵", font=("Century Gothic", 38, "bold"), fg="#ffffff", bg="#161625")
        self.end_title.pack(pady=(40, 30))

        self.end_p1_score = tk.Label(self.end_frame, text="", font=("Impact", 34), fg="#00FFFF", bg="#161625")
        self.end_p1_score.pack(pady=10)

        self.end_p2_score = tk.Label(self.end_frame, text="", font=("Impact", 34), fg="#FF4500", bg="#161625")
        self.end_p2_score.pack(pady=10)

        self.end_winner = tk.Label(self.end_frame, text="", font=("Century Gothic", 36, "bold"), fg="#FFD700", bg="#161625")
        self.end_winner.pack(pady=(40, 40))

        # --- Sidebar Canvases ---
 
        # Fixed size centered in the relative frame. 
        self.left_canvas = tk.Canvas(self.left_sidebar_frame, width=192, height=720, bg='#1a1a1a', highlightthickness=0)
        self.left_canvas.place(relx=0.5, rely=0.5, anchor=tk.CENTER)
        
        self.right_canvas = tk.Canvas(self.right_sidebar_frame, width=192, height=720, bg='#1a1a1a', highlightthickness=0)
        self.right_canvas.place(relx=0.5, rely=0.5, anchor=tk.CENTER)

        # --- Fonts ---
        self.title_font = font.Font(family="Century Gothic", size=26, weight="bold")
     
        # Fonts for the Feedback Words Pop Animation 
        self.feedback_font_large = font.Font(family="Impact", size=32, slant="italic")
        self.feedback_font_med = font.Font(family="Impact", size=26, slant="italic")
        self.feedback_font_small = font.Font(family="Impact", size=20, slant="italic") 
        
        # Fonts for the Number Score Pop Animation
        self.score_font_large = font.Font(family="Impact", size=32)
        self.score_font_med = font.Font(family="Impact", size=28)
        self.score_font_small = font.Font(family="Impact", size=24)

        self.star_font = font.Font(family="Segoe UI", size=22) 
        
        # --- Dimensions ---
        self.bar_w = 70 
        self.p_x = 96   
        self.bar_bottom = 680
        self.bar_top = 180
        self.bar_h = self.bar_bottom - self.bar_top

        # --- Titles ---
        self.left_canvas.create_text(self.p_x, 20, text="PLAYER 1", font=self.title_font, fill="#00FFFF")
        self.right_canvas.create_text(self.p_x, 20, text="PLAYER 2", font=self.title_font, fill="#FF4500")

        # --- Feedback Words & Scores ---
        # Player 1 (Pow polygon is drawn first so it stays behind text)
        self.p1_pow_bg = self.left_canvas.create_polygon([0, 0, 0, 0, 0, 0], fill="", outline="", width=3)
        self.p1_feedback_shadow = self.left_canvas.create_text(self.p_x + 3, 90 + 3, text="", font=self.feedback_font_small, fill="#000000")
        self.p1_feedback = self.left_canvas.create_text(self.p_x, 90, text="", font=self.feedback_font_small, fill="white")
        
        self.p1_num_score_shadow = self.left_canvas.create_text(self.p_x + 3, 140 + 3, text="", font=self.score_font_small, fill="#000000")
        self.p1_num_score = self.left_canvas.create_text(self.p_x, 140, text="", font=self.score_font_small, fill="white")

        # Player 2
        self.p2_pow_bg = self.right_canvas.create_polygon([0, 0, 0, 0, 0, 0], fill="", outline="", width=3)
        self.p2_feedback_shadow = self.right_canvas.create_text(self.p_x + 3, 90 + 3, text="", font=self.feedback_font_small, fill="#000000")
        self.p2_feedback = self.right_canvas.create_text(self.p_x, 90, text="", font=self.feedback_font_small, fill="white")
        
        self.p2_num_score_shadow = self.right_canvas.create_text(self.p_x + 3, 140 + 3, text="", font=self.score_font_small, fill="#000000")
        self.p2_num_score = self.right_canvas.create_text(self.p_x, 140, text="", font=self.score_font_small, fill="white")

        # --- Bars ---
        self._draw_static_gradient(self.left_canvas, self.p_x - self.bar_w/2, self.bar_top, self.bar_bottom, self.bar_w, "#FF00FF", "#00FFFF")
        self._draw_static_gradient(self.right_canvas, self.p_x - self.bar_w/2, self.bar_top, self.bar_bottom, self.bar_w, "#B22222", "#FFFF00")

        self.p1_mask = self.left_canvas.create_rectangle(self.p_x - self.bar_w/2, self.bar_top, self.p_x + self.bar_w/2, self.bar_bottom, fill="#333333", outline="")
        self.p2_mask = self.right_canvas.create_rectangle(self.p_x - self.bar_w/2, self.bar_top, self.p_x + self.bar_w/2, self.bar_bottom, fill="#333333", outline="")

        # --- Glowing Bar Caps (Leading Edge) ---
        self.p1_cap = self.left_canvas.create_rectangle(self.p_x - self.bar_w/2 - 4, self.bar_bottom - 2, self.p_x + self.bar_w/2 + 4, self.bar_bottom + 2, fill="white", outline="")
        self.p2_cap = self.right_canvas.create_rectangle(self.p_x - self.bar_w/2 - 4, self.bar_bottom - 2, self.p_x + self.bar_w/2 + 4, self.bar_bottom + 2, fill="white", outline="")
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
